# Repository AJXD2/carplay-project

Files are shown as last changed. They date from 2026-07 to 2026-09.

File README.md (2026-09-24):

# carplay Pi

A Raspberry Pi 4 CarPlay dongle box, turned into a small touchscreen
home screen with CarPlay as one app among a few others.

## Screenshots

The home screen, live on the 800x480 touchscreen. CarPlay gets the big
tile; everything else is one tap away, and the whole UI is sized for a
finger at arm's length:

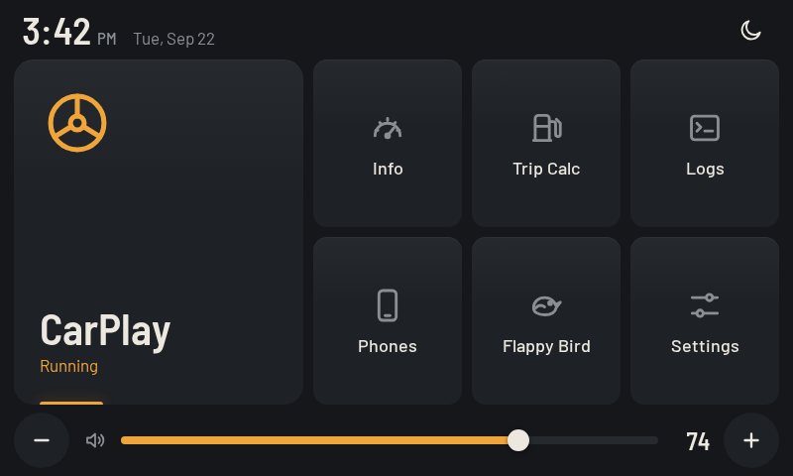
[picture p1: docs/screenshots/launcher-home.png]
Launcher home screen


CarPlay, one tile among the others:

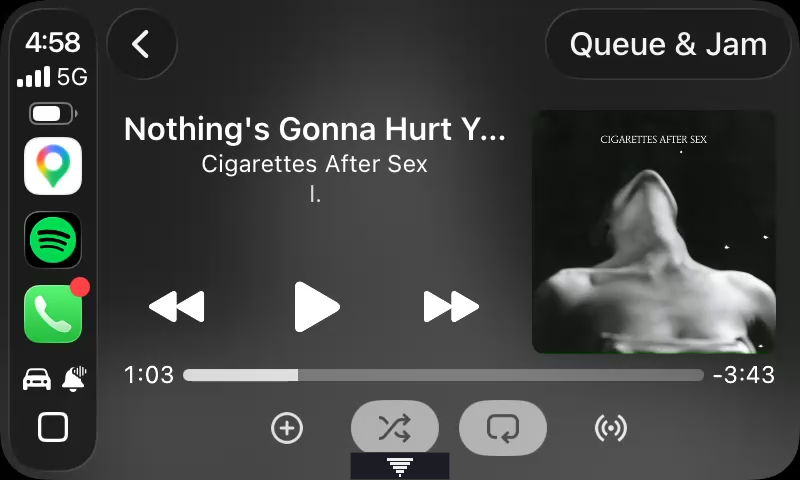
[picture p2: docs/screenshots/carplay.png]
CarPlay


| Info (live system status) | Trip Calc (fuel cost) |
|---|---|
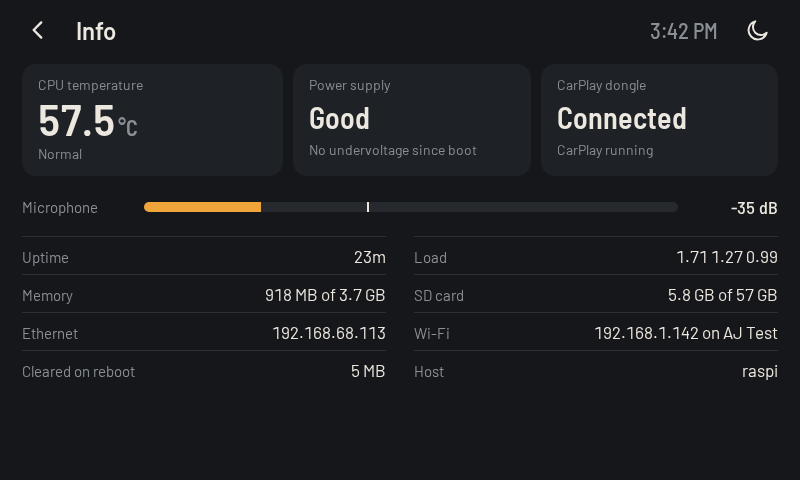
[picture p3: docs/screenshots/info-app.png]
Info
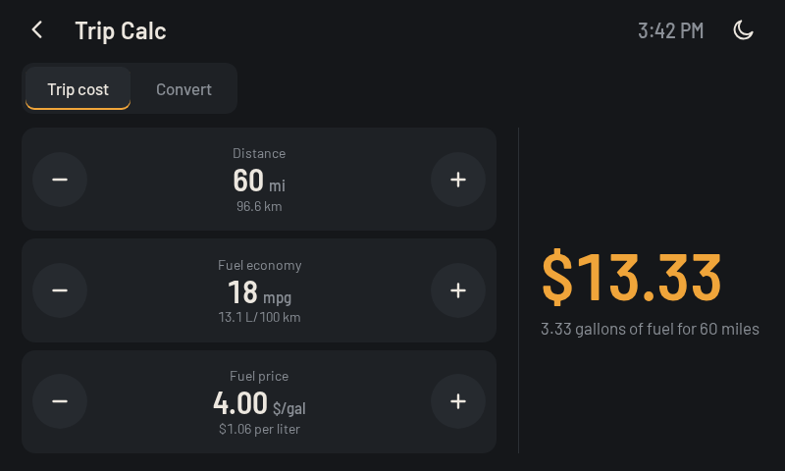
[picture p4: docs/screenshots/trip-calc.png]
Trip Calc
|  |  |

| Logs (on-screen tail) | Settings |
|---|---|
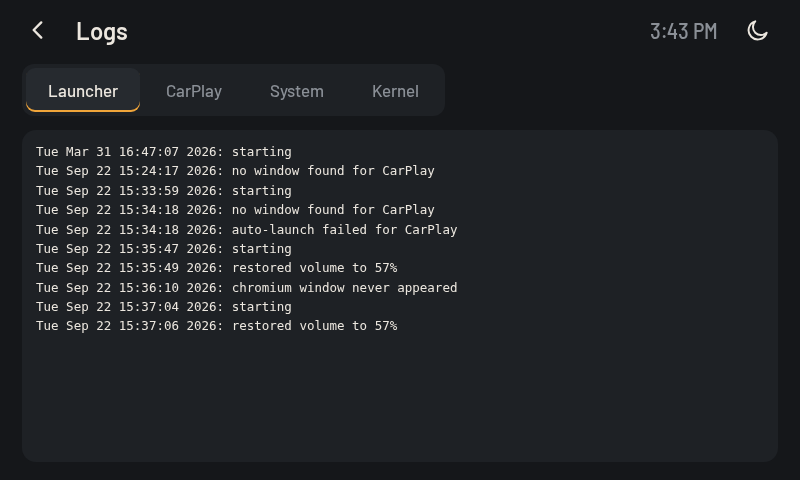
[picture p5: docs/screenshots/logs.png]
Logs
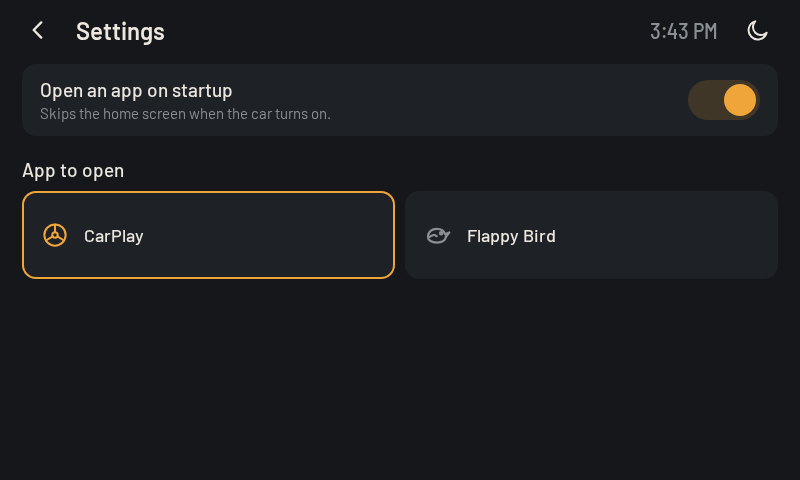
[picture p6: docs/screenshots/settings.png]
Settings
|  |  |

## What's here

- **`launcher/`**: the Chromium-kiosk home screen (Python backend +
  HTML/CSS/JS frontend) that autostarts on boot. CarPlay and Flappy Bird
  are separate apps it launches; Info, Trip Calc, Logs, Phones (the
  dongle's paired devices) and Settings are views inside the kiosk.
  Settings, trip values, volume and CarPlay's own config all survive
  reboots despite the read-only root.
- **`launcher/tools/`**: dongle tooling (web panel client, icon setter) and
  the react-carplay audio patch that fixes crackling.
- **`pi-monitor/`**: an on-screen alert system (via `dunst`) for CPU
  temp warnings and IP-address notifications, since CarPlay runs
  fullscreen with no window chrome to show that otherwise.
- **`hardware/carrier/`**: the in-truck board the Pi mounts on (power
  from the car, 4-channel amp, steering-wheel buttons, RTC, fans). Design
  in progress; see its [README](hardware/carrier/README.md).
- **`launcher/board/`**: `carrierd`, the service that runs that board
  (amp, wheel buttons, key-off shutdown, fans). Not deployed until the
  board exists.

## Quick start

Warning: the deploy scripts assume user `ajxd2` on host `raspi.local`;
edit [launcher/deploy.sh](launcher/deploy.sh) and
[pi-monitor/deploy.sh](pi-monitor/deploy.sh) for your own Pi.

```sh
ssh [user]@raspi.local            # SSH in
(cd launcher && ./deploy.sh)      # deploy launcher changes
(cd pi-monitor && ./deploy.sh)    # deploy pi-monitor changes
(cd launcher && python3 server.py --dev)   # work on the UI locally at http://127.0.0.1:8734
```

The Pi's root filesystem is **read-only at runtime**: a plain SSH edit
gets reverted on reboot. The deploy scripts handle writing through to
the real partition correctly; don't skip them.

## Full documentation

See **[INFO.md](INFO.md)** for everything else: hardware quirks, the
read-only-root persistence model in detail, networking, SSH access,
how the launcher and pi-monitor actually work, known limitations, and
a full command reference.

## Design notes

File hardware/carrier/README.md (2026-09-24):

# Carrier board (2007 4Runner head unit)

One board that turns the Pi 4 + 7" screen into a complete car radio
replacement. It bolts onto the Pi like a HAT, plugs into the truck's radio
harness, and does everything the factory radio did plus what the Pi needs:

- survives car power (reverse battery, load dump, cranking) and switches
  itself fully off with the key (a few µA left on the battery)
- powers the Pi, the screen and the fans (5 V, 6 A)
- drives the four stock speakers from the Pi's digital audio (no USB DAC,
  no ground-loop hum)
- reads the steering-wheel buttons (learn mode, any wheel)
- senses key, headlights (night mode) and reverse
- keeps the clock running with the power off
- runs two fans, and tells the Pi what it is at boot (HAT ID EEPROM)

Software for it lives in [`launcher/board/`](../../launcher/board/README.md).

## Status

| Stage | State |
|---|---|
| Schematic | Done. ERC 0 errors / 0 warnings. |
| Parts list (BOM) | Done. 148 fitted parts, every one with an LCSC number, stock checked at JLCPCB. |
| Placement | Done for the nominal Pi position. DRC: no overlaps or clearance errors. |
| Routing | Done. 0 unrouted, 0 DRC errors (silkscreen tidy pending), schematic parity 0. |
| Silkscreen tidy | Not started (cosmetic DRC items only). |
| Pi position on the screen | Measured on the real screen and confirmed with a printed fit test (see Mechanical). |
| Software | Written and tested on simulated hardware (18 tests), not installed. |
| Ordering | Not yet. |

## How it works, block by block

The schematic (`carrier.kicad_sch`, one A2 sheet, PDF in `out/carrier.pdf`)
is split into boxed sections. The same section names tag every part
(hidden `Section` field) so the board layout can find each block.

| Section | Parts | What it does |
|---|---|---|
| Harness | J1, Molex Micro-Fit 3.0 2x10 vertical | Truck wiring in; plug faces the firewall |
| Input protection | LM74800-Q1 + 2x BUK7Y4R8-60E + SMBJ33CA | Reverse-battery block, cuts off above 35.1 V (load dump), slow soft start (~2.5 V/ms). Its enable (SYS_EN) is the board's master switch |
| 5 V buck | LM61460-Q1, 4.7 µH | 5 V / 6 A at 400 kHz for Pi, screen (through GPIO pins 2/4 and the display's pogo pins), fans. Turns on at 6.0 V, off at 4.3 V, so it rides through cranking |
| 3.3 V | TLV75533 | Amp logic, ADC, RTC, EEPROM, clocks |
| Power hold + sensing | diodes, RC, 3x MMBT3904 | SYS_EN = key OR the Pi's hold line. Key/lights/reverse become active-low 3.3 V inputs |
| Amplifier | TAS6424E-Q1 | 4 x BTL, about 25 W/ch into 4 Ω at 14.4 V, 2.1 MHz switching, I2C controlled (0x6A) |
| Output filters | 8x 3.3 µH + 1 µF + 1 nF | Reconstruction filter per speaker leg (TI reference values) |
| Audio clocks | 12.288 MHz oscillator + PCM1808-Q1 | The board is the audio clock master (see decisions) |
| Mic input | 3.5 mm jack J4 (PJ-320D) into the PCM1808 | Electret car mic for calls and Siri: bias from 3.3 V, ESD and RF filtering at the jack, the PCM1808's ADC sends it to the Pi on GPIO20. Mic on the tip; ring and sleeve grounded |
| Status LEDs | 3 red 0603 (D8-D10), tagged 12V / 5V / PI | Which power stage is alive: protected 12 V, the 5 V rail, and the Pi holding the board on |
| Steering wheel + battery ADC | ADS1115 (0x48) | Two ladder inputs (1k pull-ups, ESD, RC filter), battery voltage on AIN2 |
| RTC + ID EEPROM | DS3231SN + CR2032 (0x68), CAT24C32 (0x50) | Clock through power-off; HAT ID per the Raspberry Pi HAT design guide |
| Pi | J2, 2x20 socket on the underside | Mates with the Pi's header |
| Fans | 2x 4-pin headers, 2N7002 each | PWM from the Pi, inverted by the FET; tach readback |
| Debug + mounting | UART header (not fitted), H1-H6 | Pi holes isolated per HAT spec; heatsink screws grounded |

## Design decisions and why

- **Class-D amp fed digitally (I2S).** The old setup went through a USB
  sound card; digital audio straight to the amp removes that and the
  ground-loop path. The TAS6424E-Q1 is automotive (AEC-Q100), survives
  40 V load dump, and was the only in-stock 4-channel part with digital
  input at JLCPCB.
- **The board is the audio clock master.** The Pi's PCM block carries only
  two channels, and the TAS6424 needs a real master clock (128-512 x the
  sample rate) outside TDM mode. So a 12.288 MHz oscillator drives the amp's
  MCLK directly and a PCM1808-Q1 in master mode (MD1 = MD0 = high, strapped,
  no software) divides it to the bit clock (64 fs) and frame clock
  (48 kHz). All three come from one crystal and cannot drift apart. The Pi
  runs its I2S port as a clock consumer. Consequences: audio is fixed at
  48 kHz (PulseAudio resamples), and the rear speakers play the same stereo
  as the front (SDIN1 and SDIN2 share the data); the fader and balance use
  the amp's per-channel volume. The CS2100 clock chip originally planned was
  dropped: JLC only stocks the -10 to 70 °C grade.
- **One master switch.** The LM74800's enable turns the whole board off.
  SYS_EN is the OR of the key (with a ~5 s RC grace period so a crank before
  the Pi boots does not cut power) and the Pi's own hold line (GPIO26). The
  Pi decides when to power off: key off for 8 s, then it shuts down cleanly,
  drops the hold line, and the board switches off about 2 s later. A hung Pi
  is reset by its watchdog, which also drops the hold line.
- **Steering wheel by learn mode.** Toyota wheels are resistor ladders on
  two wires. Instead of hard-coding resistor values, the software asks for
  each button once and remembers what it reads. It refuses two buttons it
  cannot tell apart.
- **Harness as one latching plug.** Every truck wire ends in one Micro-Fit
  plug (like a PC's ATX connector) that clicks into the board. 8.5 A per
  contact; 12 V and ground use several pins each.
- **Heatsink copied from TI's evaluation board.** The amp's thermal pad is
  on top of the chip. TI's EVM uses a custom 20 x 41.4 mm finned heatsink
  screwed down with M3 screws and Arctic Silver paste; ours is the same
  footprint with fins sized for CNC machining (`tools/heatsink.py`). Its
  feet sit on grounded pads, which grounds the heatsink as TI requires.
- **Part choices for car conditions.** Every IC is rated to at least 85 °C.
  Caps upstream of the 35 V cutoff are 100 V (the TVS can clamp to 53 V),
  the rest of the 12 V side is 50 V X7R. Speaker-filter 1 nF caps are C0G.
  Boot caps are 0603 (fit the amp's 0.635 mm pin pitch; datasheet asks for
  X7R ≥ 16 V, these are 50 V).
- **Fans fail safe.** The PWM FET's gate pull-down leaves the fans at full
  speed whenever the Pi is not driving them.

Full calculations (divider values, time constants, cut-off voltages) are
written as notes on the schematic next to each circuit.

## Mechanical

**Display:** Hosyond 7" DSI, **164.9 x 102.0 mm, 12.25 mm thick** per the
manufacturer's drawing (`datasheets/hosyond/`). The board uses the same
outline. Its own four mounting holes sit 5 mm in from each corner (154.89 x
91.92 mm apart): the enclosure screws into those, before the Pi and board go
on (the board sits ~18 mm above the screen's back, clear of the screw heads).

**Where the Pi sits on the screen.** First estimated from Hosyond's product
photo (the Pi's 58 x 49 mm hole pattern set the scale), then **measured on
the real screen** on 2026-09-24 with a printed fit plate and calipers, Pi
board edge to screen edge:

| Pi edge | To the screen edge |
|---|---|
| Ports side (USB/Ethernet) | 36.65 mm |
| Display ribbon side | 43.40 mm |
| GPIO side | 15.35 mm |
| USB-C / HDMI side | 31.45 mm |

The sums (165.05 x 102.80, all values rounded down) match the 165 x 103
screen. Left/right differed from the photo estimate by 1.35 mm, up/down by
under 0.2 mm. The plate's screw holes, header window and port notch all
lined up.

| Viewed from the back, from the display's top-left corner | mm |
|---|---|
| Upper Pi holes | x 60.15 and 118.15, y 35.1 |
| Lower Pi holes | x 60.15 and 118.15, y 84.1 |
| Pi outline | x 36.65 to 121.65, y 31.6 to 87.6 |
| Orientation | rotated 180°: GPIO header at the bottom, USB/Ethernet toward the right of the screen as seen from the front |

The manufacturer's drawing then confirmed the Pi holes at 60.36 / 118.36
mm from the screen's left edge and 35.19 / 84.19 mm from its top (within
0.2 mm of the measurements), and set the final outline.

How the correction is applied: the board is referenced to the Pi, so the
Pi, every part, the notch and the cable slot stay where they are and only
the outer outline moves (`OUTLINE_SHIFT` in `tools/place.py`). All copper was
routed at least 3 mm from the outer edges for exactly this; with the final
outline the edge margin is 2.5 mm.

**Board shape.** The Pi is mid-screen, so its USB/Ethernet block (13.5 mm
tall Ethernet jack, board sits 11 mm above the Pi) is ~30 mm in from the
display's edge. The board has a notch from the port block to the left edge
(back view): the jacks clear it and cables can reach them. A slot next to
the Pi's DSI connector clears the display ribbon (HAT spec position).

**Stack-up** (from the screen's glass, toward the firewall):

| Layer | z (mm) | Source |
|---|---|---|
| Display module | 0 to 6.0 | **assumed**, measure |
| Pi standoffs | 6.0 to 12.0 | **assumed**, measure |
| Pi 4 board | 12.0 to 13.6 | Pi spec |
| Header base + socket | 13.6 to 24.6 | 2.5 + 8.5 mm, HAT standard (11 mm M2.5 standoffs) |
| Carrier board | 24.6 to 26.2 | 1.6 mm |
| Tallest parts on it | to ~39 | 470 µF cap 12.5 mm, harness plug + mated housing |
| Heatsink fins | to 56.5 | 30.2 mm heatsink |

Overall **165 x 103 x 56.5 mm**. The heatsink sets the depth; shorter fins
(e.g. 15 mm) save ~13 mm at some cooling cost, which the fans make up.

**Fit test before ordering:** `tools/fit_plate.py` writes
`mech/fit_plate.stl`, a 1.6 mm plate with the board's exact outline, notch,
cable slot, Pi and heatsink holes and a window for the Pi header. Print it
text side up, mount it on the Pi with the 11 mm standoffs, and check the
edges against the screen and the holes against the standoffs.

**3D model:** `tools/assembly.py` builds display + Pi 4 + board + heatsink
(`mech/assembly.step`, `mech/assembly.stl`; generated, not committed).
Review images: `out/3d/*.png` via `tools/render3d.py`.

## Wiring the truck

The truck has three plugs behind the radio: two yellowish ones (power,
speakers; what the Metra harness mates with) and a white 20-pin one that
carries the steering-wheel wires. Build one Micro-Fit plug that gathers
them all:

- Power and speakers: the Metra harness wires, or the Klintotour adapter
  (which also has the white 20-pin plug). Either way the loose ends go into
  the Micro-Fit plug; nothing on the truck gets cut.
- Steering wheel: the Klintotour adapter's white-plug wires, cut from its
  16-pin end. Identify KEY1 and KEY2 with a meter (see below).
- Reverse: tap the truck's reverse-light wire (Posi-Tap) and run a wire to
  pin 10.

To build the plug: solder each wire to a pre-crimped Micro-Fit lead,
heat-shrink it, and push the pin into its numbered hole until it clicks.
Pin n sits directly above pin n+10. The speaker order (FR, FL, RR, RL) is
not a typo: it matches the amp's output order on the board, so the four
speaker tracks run straight to the plug without crossing.

| Pin | Signal | Typical wire colour |
|---|---|---|
| 1, 11 | +12 V constant | Yellow |
| 2, 12, 19 | Ground | Black |
| 7 | Key / accessory | Red |
| 17 | Headlights on (illumination) | Orange |
| 10 | Reverse (+12 V in reverse) | Pink "BACK" on the adapter, or your own wire |
| 8 | Steering wheel wire 1 (seek, volume) | KEY1 |
| 18 | Steering wheel wire 2 (mode) | KEY2 |
| 9 | Steering wheel ground | if separate; otherwise tie to ground |
| 3 / 13 | Front right + / − | Gray / gray-black |
| 4 / 14 | Front left + / − | White / white-black |
| 5 / 15 | Rear right + / − | Purple / purple-black |
| 6 / 16 | Rear left + / − | Green / green-black |
| 20 | Not used | |

Finding KEY1 / KEY2: adapter plugged into the truck, key off, meter on
ohms between each candidate wire and ground. The wire whose reading
changes with seek/volume is KEY1 (pin 8); the one that drops near 0 Ω on
Mode is KEY2 (pin 18). Earlier measurements on the purple SWC wire: seek+
~0 Ω, seek− 331 Ω, vol+ 100 Ω, vol− "3.111" (unit unclear). Learn mode
makes the exact values irrelevant.

Blue wires (power antenna, amp turn-on) are not used.

## Pi GPIO map

| Header pin | BCM | Net | Use |
|---|---|---|---|
| 2, 4 | 5V | +5V | Board powers the Pi (and the screen through its pogo pins) |
| 1, 17 | 3V3 | (unused) | The board makes its own 3.3 V |
| 3, 5 | GPIO2/3 | I2C_SDA/SCL | Amp 0x6A, ADC 0x48, RTC 0x68 (Pi has 1.8k pull-ups) |
| 27, 28 | ID_SD/SC | ID_SDA/SCL | HAT EEPROM 0x50 (3.9k pull-ups on the board) |
| 12 | GPIO18 | I2S_BCLK | Bit clock, **input** (board is master) |
| 35 | GPIO19 | I2S_FSYNC | Frame clock, **input** |
| 40 | GPIO21 | I2S_DOUT | Audio data to the amp |
| 32, 33 | GPIO12/13 | FAN1/2_PWM | Hardware PWM, 25 kHz, inverted |
| 36, 7 | GPIO16/4 | FAN1/2_TACH | Tach, 2 pulses/rev |
| 11 | GPIO17 | ~ACC_ON | Key on (active low) |
| 13 | GPIO27 | ~LIGHTS_ON | Headlights (active low, may be PWM-dimmed) |
| 38 | GPIO20 | I2S_DIN | Mic audio from the PCM1808, **input** |
| 26 | GPIO7 | ~REVERSE | Reverse gear (active low) |
| 37 | GPIO26 | PI_HOLD | Keeps the board powered while high |
| 15, 16 | GPIO22/23 | ~AMP_STBY/~AMP_MUTE | Amp control |
| 18, 22 | GPIO24/25 | ~AMP_FAULT/~AMP_WARN | Amp status (open drain) |
| 31 | GPIO6 | ~ADC_ALERT | ADC ready (unused by software for now) |
| 29 | GPIO5 | ~RTC_INT | RTC alarm |
| 8, 10 | GPIO14/15 | UART_TX/RX | Debug header (not fitted) |

## Shopping list (besides the board)

From DigiKey (genuine Molex; Amazon does not carry the 20-way housing):

| Qty | Part | Link |
|---|---|---|
| 2 | Micro-Fit 3.0 2x10 plug housing, Molex 43025-2000 | [DigiKey](https://www.digikey.com/en/products/detail/molex/0430252000/531408) |
| 25 | Micro-Fit pre-crimped lead, socket + 300 mm 18 AWG, Molex 2147611124 | [DigiKey](https://www.digikey.com/en/products/detail/molex/2147611124/12353036) |
| opt. | Micro-Fit extraction tool, Molex 11-03-0043 (the Amazon "11-03-0044" tools are Mini-Fit Jr, wrong size) | [DigiKey](https://www.digikey.com/en/products/detail/molex/0011030043/252489) |

From Amazon:

| Qty | Part | Link |
|---|---|---|
| 1 | Klintotour Toyota adapter (for the white steering-wheel plug) | [B0FBRNCNPD](https://www.amazon.com/dp/B0FBRNCNPD) |
| 1 | CR2032 | [B07G7KRQQ5](https://www.amazon.com/dp/B07G7KRQQ5) |
| 1 | M2.5 standoffs, 11 mm body + 6 mm thread | [B07KM27KC6](https://www.amazon.com/dp/B07KM27KC6) |
| 2 | Noctua NF-A4x10 5V PWM (each includes an extension cable) | [B07DXS86G7](https://www.amazon.com/dp/B07DXS86G7) |
| 1 | Posi-Tap 18-24 AWG | [B01HSBYX3I](https://www.amazon.com/dp/B01HSBYX3I) |
| 1 | 18 AWG wire (reverse run) | [B07D74RGVM](https://www.amazon.com/dp/B07D74RGVM) |
| 1 | Heat-shrink assortment | [B01MFA3OFA](https://www.amazon.com/dp/B01MFA3OFA) |
| opt. | 4-pin PWM fan extensions | [B0CNLDNZB2](https://www.amazon.com/dp/B0CNLDNZB2) |

With the board order (JLCPCB): the heatsink as a CNC part from
`mech/heatsink.step` plus `mech/heatsink_drawing.pdf` (threads, tolerances):
6061-T6 aluminium, **no surface finish** (anodising would insulate it; it is
grounded through its feet), two M3 threads in the feet, foot height
2.20 +/-0.05 mm. Also needed: thermal paste (Arctic MX-4 or similar) and two M3 x 5 mm
screws (they go up through the board into the heatsink).

## Files

| Path | What |
|---|---|
| `carrier.kicad_sch` / `.kicad_pcb` / `.kicad_pro` | KiCad 10 project (generated, see below) |
| `lib/carrier.kicad_sym`, `lib/carrier.pretty/` | Custom symbols and footprints |
| `lib/ref/` | EasyEDA/JLC reference symbols and footprints used to check pinouts |
| `datasheets/` | Every datasheet used, plus the HAT mechanical drawing and TI's EVM guide |
| `mech/heatsink.step`, `.stl` | Heatsink for CNC |
| `tools/` | Generators and checks (below) |
| `out/` | Renders, PDF, BOM, reports (generated, not committed) |

## Regenerating everything

The schematic and board are produced by scripts, not edited by hand, so
every value and position is reviewable in one place. KiCad runs as a
Flatpak; `kicad-cli` is a wrapper in `~/.local/bin`. The Python virtualenv
`.venv` holds `easyeda2kicad`, `cadquery` and `matplotlib`.

```bash
cd hardware/carrier
python3 tools/make_symbols.py            # lib/carrier.kicad_sym
python3 tools/gen_sch.py                 # carrier.kicad_sch (part numbers included)
python3 tools/render.py                  # out/sch/full.png, plus crops: render.py name x1 y1 x2 y2
kicad-cli sch erc -o out/erc.rpt carrier.kicad_sch
kicad-cli sch export pdf -o out/carrier.pdf carrier.kicad_sch
kicad-cli sch export bom --fields 'Value,Reference,Footprint,LCSC,MPN,Manufacturer,${QUANTITY},${DNP}' \
  --labels 'Comment,Designator,Footprint,LCSC,MPN,Manufacturer,Qty,DNP' \
  --group-by 'Value,Footprint,LCSC,${DNP}' --exclude-dnp -o out/bom_jlcpcb.csv carrier.kicad_sch

tools/build_board.sh                     # placement, planes, hand routes, Freerouting, finish, DRC (~20 min)
tools/build_board.sh noauto              # stop before the autorouter
flatpak run --command=python3 org.kicad.KiCad tools/dump_pcb.py   # then:
.venv/bin/python tools/view_pcb.py NAME [x0 y0 x1 y1] [--nets TEXT] [--labels]   # out/pcb/NAME.png
.venv/bin/python tools/fit_plate.py      # mech/fit_plate.stl

.venv/bin/python tools/heatsink.py       # mech/heatsink.step/.stl
kicad-cli pcb export step --subst-models --force -o mech/carrier_board.step carrier.kicad_pcb
.venv/bin/python tools/assembly.py       # mech/assembly.step/.stl
.venv/bin/python tools/render3d.py       # out/3d/*.png
```

What each script owns:

- `make_symbols.py`: custom symbols (TAS6424, LM61460, LM74800, DS3231,
  PCM1808, harness, Pi header). Pin numbers and names were checked against
  datasheets / EasyEDA each time a symbol was rearranged.
- `gen_sch.py` + `schlib.py`: the schematic. Each section is a function
  placed at an anchor; `PARTS` maps (value, footprint) to MPN /
  manufacturer / LCSC. Part UUIDs are derived from references, so reruns are
  byte-identical and the board stays linked to the schematic.
- `gen_pcb.py` + `place.py`: board outline, 4-layer stackup, JLC design
  rules, net classes and placement. `place.py` holds the Pi position, the
  notch/slot geometry and every block's layout, with parts found by
  Section field and nets.
- `route.py`: everything that carries current or needs care, locked so the
  autorouter works around it. In1 is solid GND; In2 is split into
  +12V_PROT (protection, amp, buck input) and +5V (buck output, Pi, LDO,
  clocks, fans). Top-layer pours for the battery path, VMID, buck VIN/PGND/SW
  and output, amp PVDD and the Pi's 5 V pins. Hand-routed amp outputs (P legs
  on top, M legs dropped to the bottom under the coils) and speaker lanes
  (1 mm, nested so none cross). Every GND pad gets its own via to In1, and
  +5V/+12V pads over their In2 region likewise. The LM74800's 0.5 mm pins
  and a few tight nets are routed by `maze.py` (a small grid router).
  Nothing copper within 3 mm of the outer edge.
- `autoroute.py` exports to Freerouting (with keepouts guarding the pours)
  and imports the result; `finish.py` maze-routes anything left open.
- `heatsink.py`, `assembly.py`, `render3d.py`: mechanical.

## Verification so far

- ERC: 0 errors, 0 warnings.
- Netlist check: every Pi GPIO lands on its intended net; amp pins, speaker
  filters and clock nets checked net by net.
- Board: 0 schematic-parity issues; no courtyard overlaps or clearance
  errors; parts clear of the Pi socket's solder pins by 3 mm; only parts
  under 2.2 mm under the heatsink.
- BOM: 148 fitted parts, all LCSC numbers present and in stock when chosen
  (2026-09-22/24).
- Pi socket orientation: pin 1 over the Pi's pin 1, checked by pad position
  (a mirrored socket would put 5 V on the wrong pins).
- Software: 18 tests on simulated hardware, including the GPIO request
  struct compared byte for byte with `<linux/gpio.h>`.

## Open items

1. ~~Fit check~~: done 2026-09-24, the corrected outline (`mech/fit_frame.stl`)
   fits the screen, screw holes, header and port notch exactly.
2. Measure display thickness and the display-to-Pi standoff height (3D
   model only).
3. Tidy silkscreen; add the harness pin table next to J1.
4. Final review (renders, BOM, cost), then order: board + assembly + CNC
   heatsink from JLCPCB.
5. On first power-up: confirm the react-carplay window class used for
   steering-wheel keys, run learn mode, check amp start-up and fault
   handling on real hardware, and check the mic capture path (the overlay
   puts two dummy codecs on one I2S link; set mic gain in software).

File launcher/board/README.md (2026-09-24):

# carrierd: carrier board services

Software for `hardware/carrier`: the TAS6424 amp, steering-wheel buttons,
key-off shutdown, headlights/reverse inputs and the fans. Standard library
Python only; the I2C and GPIO access uses the kernel interfaces directly.

| File | What it does |
|---|---|
| `carrierd.py` | Daemon: main loop, actions, local API on `127.0.0.1:8735` |
| `tas6424.py` | Amp bring-up (datasheet order), fader, fault recovery, thermal trim |
| `swc.py` | ADS1115 reader, button decoder with hold-repeat, learn mode |
| `power.py` | Key-off timer (rides out cranking), PWM-dimmer averaging, debounce |
| `fans.py` | Fan curve, tach RPM (the PWM is inverted by the board's FET) |
| `hw.py` | I2C (`I2C_RDWR`), GPIO chardev v2, sysfs PWM, plus simulated twins |
| `sim.py` | Register models of the TAS6424 and ADS1115 |
| `system/` | `config.txt` lines, the I2S overlay, the systemd unit |

Test on any machine (the GPIO test compiles against `<linux/gpio.h>` to
check the struct layout byte for byte):

    cd launcher && python3 -m unittest board.test_board -v
    python3 -m board.carrierd --sim        # runs the loop on simulated hardware

## Install (once the board is built)

Not part of `deploy.sh` yet, since nothing here should run without the board.

1. Append `system/config.txt` to `/boot/firmware/config.txt`.
2. `sudo apt install device-tree-compiler`, then
   `sudo dtc -@ -I dts -O dtb -o /boot/firmware/overlays/carrier-audio.dtbo system/carrier-audio-overlay.dts`.
3. PulseAudio must run at the board's fixed 48 kHz: in `/etc/pulse/daemon.conf`
   set `default-sample-rate = 48000` and `alternate-sample-rate = 48000`.
4. Copy `board/` to `/home/ajxd2/launcher/board`, install
   `system/carrierd.service` to `/etc/systemd/system/`, `systemctl enable carrierd`.
5. Persist all of the above to `/media/root-ro` (see INFO.md), reboot.
6. Learn the steering wheel: `curl -X POST 127.0.0.1:8735/learn/start`, press
   each button as `GET /state` prompts (`/learn/skip` for buttons the wheel
   lacks). A launcher screen for this comes with the board bring-up.

Things to confirm on the real hardware: the CarPlay window class used for
key injection (`carplay_window_class`, default `react-carplay`) and the
wheel's button readings.

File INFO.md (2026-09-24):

# carplay Pi

Notes and tooling for the Raspberry Pi 4 CarPlay dongle box. This repo
exists because the Pi's root filesystem is read-only at runtime, so
nothing done directly on the device persists unless you go through one
of the methods documented below. Read this before you SSH in and start
changing things: it *will* get reverted on reboot otherwise.

See [README.md](README.md) for an overview and screenshots.

## Hardware / OS

- **Raspberry Pi 4**: USB-C port is power-only, no OTG/gadget mode. USB-A
  ports are host-only too. There is no way to get a terminal over a USB
  cable on this board; use the network or GPIO UART.
- Raspberry Pi OS (Debian trixie), kernel `6.12.47+rpt-rpi-v8`.
- Hostname: `raspi`. User: `ajxd2`.
- Power: needs a genuine 5.1V/3A USB-C PD supply into a wall outlet. A
  computer's USB port or a cheap/thin cable will trigger an undervoltage
  warning and throttle the CPU / risk SD corruption. There's no
  "raise the voltage" fix, it's a current-delivery problem, not a
  software setting. (`avoid_warnings=1` in `config.txt` only hides the
  icon, doesn't fix the actual undervoltage: don't use it as a fix.)

## Read-only root (`overlayroot`): the most important thing to understand

The Pi boots with `overlayroot="tmpfs:recurse=0"` (see
`/etc/overlayroot.conf`). This means:

- The real filesystem (`/dev/mmcblk0p2`, ext4) is mounted **read-only**
  at `/media/root-ro`.
- Everything else (`/`, `/home`, `/etc`, ...) is a **tmpfs overlay** on
  top of that, `upperdir=/media/root-rw/overlay`.
- Anything written while the Pi is running normally (`apt install`,
  editing a config file, anything) goes into that tmpfs upper layer
  and is **gone on the next reboot or power cycle**.

This is intentional and correct for a device that gets its power cut
abruptly (car ignition off) instead of shut down cleanly. It protects
the SD card from corruption. Don't disable it permanently; work with
it instead.

### How to make a change actually persist

Two ways, both write straight to the real ext4 partition, bypassing
the tmpfs overlay entirely:

**A. Over SSH, while the Pi is running (preferred, no physical access needed):**

```sh
# Remount the real partition read-write:
ssh ajxd2@raspi.local 'sudo mount -o remount,rw /media/root-ro'

# Then write files under /media/root-ro/... instead of the normal path, e.g.:
ssh ajxd2@raspi.local 'sudo tee /media/root-ro/home/ajxd2/some-file'

# For anything needing a proper package-manager/root context (apt installs etc),
# use the overlayroot-chroot helper instead of remounting manually:
ssh ajxd2@raspi.local 'sudo overlayroot-chroot apt-get install -y <pkg>'
# (No "--" before the command: overlayroot-chroot <cmd...> directly.)

# Best-effort remount back to read-only when done:
ssh ajxd2@raspi.local 'sudo mount -o remount,ro /media/root-ro'
```

**Known kernel quirk:** the remount back to `ro` frequently fails with
`mount point is busy` while the overlay is actively mounted on top of
it. This is non-fatal, it just means the real partition stays
writable for the rest of this boot session (same power-loss-corruption
risk as a normal filesystem until next reboot). It always resets
cleanly to read-only on the next boot regardless. If you want the
protection back immediately, `sudo reboot`.

**Another quirk:** overlayfs caches directory listings the first time
something is looked up. If you install a new package (new files
appearing in an already-accessed directory like `/usr/bin`), those new
files **will not show up in the live session**, you have to `sudo
reboot` for the overlay to remount fresh and pick them up. Writing a
brand-new file into a path that's never been touched this boot (e.g. a
new subdirectory under `/home/ajxd2/`) *does* show up live immediately
via the overlay's fallthrough-to-lower behavior. When in doubt, reboot
to be sure.

**B. Offline, by pulling the SD card:**

Mount it on another machine (rootfs partition is `ext4`, boot partition
is `vfat`), edit files directly, unmount, put it back. Slower, but
useful if the Pi won't boot / network is unreachable / you need to fix
something SSH-related itself (like `authorized_keys`).

```sh
lsblk -f                              # find the device, e.g. /dev/sdb
udisksctl mount -b /dev/sdb2          # mounts rootfs at /run/media/$USER/rootfs
udisksctl mount -b /dev/sdb1          # mounts boot partition at .../bootfs
# ... edit files under /run/media/$USER/rootfs/... ...
udisksctl unmount -b /dev/sdb2
```

If your local user has the same UID as `ajxd2` on the Pi (id 1000),
you can write to `ajxd2`-owned files without `sudo` at all.

## Networking

- `systemd-networkd` (enabled) does DHCP on both `eth0` and `wlan0`.
  Configs at `/etc/systemd/network/10-eth0.network` and
  `20-wlan0.network`. **Not** `dhcpcd` (present but unused/not enabled).
- Wi-Fi auth is `wpa_supplicant@wlan0.service` (enabled), config at
  `/etc/wpa_supplicant/wpa_supplicant-wlan0.conf` (root-only, `600`).
- `NetworkManager.service` is also enabled but effectively inert:
  `system-connections/` is empty and `NetworkManager.conf` sets
  `managed=false` for ifupdown. It's a leftover, not what's actually
  bringing interfaces up. Ignore it.
- `avahi-daemon` was **masked** (`/etc/systemd/system/avahi-daemon.service`
  symlinked to `/dev/null`) out of the box, which is why `raspi.local`
  didn't resolve. We unmasked and enabled it (done, persisted). If a
  fresh image ever has this problem again:
  ```sh
  sudo rm /media/root-ro/etc/systemd/system/avahi-daemon.service
  sudo ln -s /lib/systemd/system/avahi-daemon.service \
    /media/root-ro/etc/systemd/system/multi-user.target.wants/avahi-daemon.service
  ```
  (or the SSH-live equivalent using `overlayroot-chroot`).

## SSH access

- `authorized_keys` lives at `/home/ajxd2/.ssh/authorized_keys` (was
  empty, that's why a new machine couldn't get in). Add a new laptop's
  key by appending its `~/.ssh/id_ed25519.pub` to that file (through
  one of the persistence methods above, not a plain live SSH edit, or
  it'll disappear on reboot).
- `PasswordAuthentication` is commented out (defaults to whatever
  sshd's compiled default is, currently pubkey-only in practice since
  no password login has worked). Pubkey is the supported path.
- The `ajxd2` account has **passwordless sudo**, and UID 1000 matches a
  typical single-user Linux desktop, which is how the SD-card-editing
  trick above works without needing the Pi's password at all.

## The CarPlay dongle itself (Carlinkit CPC200-CCPA)

The physical dongle enumerates as USB `1314:1521` (`Magic Communication
Tec.` / `Auto Box` in the descriptors, broadcasting as `AutoKit-8169`
over WiFi/BT), and is a genuine Carlinkit CPC200-CCPA (confirmed from
the printing on the physical unit) -- an i.MX6UL-based embedded Linux
board, 16MB flash. It reports `boxType: YA`, `productType: A15W`,
`hwVersion: YMA0-WN16-0003`, software `2025.02.25.1521CHY`.

`react-carplay`/`node-carplay` (the app this repo runs) talks to it
over a simple bulk-USB wire protocol reverse-engineered upstream in
`rhysmorgan134/node-CarPlay`'s `src/modules/messages/{common,sendable,
readable}.ts`. Worth knowing if you ever need to script against the
dongle directly (`python3-usb`, install via `sudo overlayroot-chroot
apt-get install -y python3-usb`, works fine for this since it's just
bulk transfers on a vendor-specific interface):

- **Reads available**: manufacturer/serial (USB descriptor), software
  version, box identity/config including the full **paired-device
  list** (`BoxInfo.DevList` -- MAC, name, index, per device), a
  separate raw `BluetoothPairedList` string, box's own WiFi/BT name,
  a live HiCar pairing link, and now-playing media (song/artist/album
  art -- this is genuinely live personal data, be careful taking
  screenshots of a running session).
- **Writes available**: night mode, WiFi band, media transport
  commands, accept/reject call, and file-based cosmetic config
  (`SendFile` to `/etc/box_name`, `/etc/airplay.conf`,
  `/etc/icon_*.png` etc) -- see `launcher/tools/set_dongle_icon.py`,
  which sets a custom name + icon on the phone's CarPlay home-screen
  tile using exactly this mechanism. **File writes to `/etc/` on the
  dongle appear to only take effect after a physical power-cycle of
  the dongle itself** (unplug/replug), not just a CarPlay app restart.
- **Device removal is NOT in the USB protocol -- but it exists in the
  dongle's own web admin panel.** Over the USB wire protocol there is no
  remove/forget command (confirmed: tried the documented set plus
  `BoxSettings` (0x19) writes carrying `DevList`/`delDevList`/`removeDev`
  fields, plus `SendFile` to guessed paired-store paths, plus a real
  physical power-cycle -- the `DevList` survived all of it). The removal
  capability lives instead in the dongle's **built-in HTTP admin panel**,
  which the USB investigation never looked at:
  - The dongle runs a WiFi AP `AutoKit-8169` (WPA2-PSK, password
    `12345678`, BSSID `00:e0:4c:64:1b:24`). Joining it gets a DHCP lease
    on **`192.168.43.0/24`** (this unit -- *not* the `192.168.50.x` the
    generic Carlinkit docs claim), with the panel at
    **`http://192.168.43.1`** (a Vue SPA). The Pi has a single `wlan0`,
    so joining this AP drops the Pi's own network unless it also has
    `eth0` up -- pin SSH to the `eth0` IP first, then repurpose `wlan0`.
  - The panel's entire API is one endpoint: `POST /cgi-bin/server.cgi`,
    multipart form fields `cmd` / `item` / `val` / `ts` (ms) / `sign`
    (md5, computed by the panel JS). Observed calls:
    - **Remove one paired device:** `cmd=set, item=delDev,
      val=<MAC>` -> `{"err":0}`. Verified: removing `A4:CF:99:0B:A3:16`
      dropped the box's `DevList` from 4 to 3, confirmed by an
      independent USB `BoxInfo` read afterward.
    - Read full state (incl. `DevList`, `Settings`, `BoxInfo`):
      `cmd=infos`.
    - Reboot the dongle: `cmd=restart`.
  - Using the panel UI from a phone (join the AP, browse to
    `192.168.43.1`, delete the device) is the easy path -- the JS signs
    requests for you. It can also be scripted headless: the signing was
    reverse-engineered and `launcher/tools/ccpa_panel.py` implements it
    (see the full API section below).
  - Simpler alternatives that also work: the phone's own Settings ->
    General -> CarPlay -> (car) -> "Forget This Car", or a full wipe via
    the panel's factory reset / the physical pinhole reset button (clears
    ALL pairings + WiFi/BT config, so every phone re-pairs).
- **Don't bother with alternate/custom firmware.** Carlinkit added an
  activation-lock mechanism (`/etc/uuid_sign`) after community
  reverse-engineering became known to them; a firmware that fails
  activation has no known unlock path. There's also no documented live
  root/shell access to this hardware (no UART/SSH/telnet), only
  hardware flash programming, which isn't worth the bricking risk --
  especially now that device management is reachable through the stock
  web panel above without touching firmware at all.

### The dongle web panel API (`server.cgi`) -- full map

The panel at `http://192.168.43.1` is a Vue SPA; its entire backend is
one endpoint, `POST /cgi-bin/server.cgi` (multipart/form-data). Client:
`launcher/tools/ccpa_panel.py` (stdlib-only, works headless or through
an `ssh -D` SOCKS tunnel with `--proxy socks5h://127.0.0.1:1080`).

**Request signing** (reversed from `PublicV2.js` `signFormData`, verified
byte-for-byte against captured requests):

- Every request carries `ts` (epoch ms) and `sign`.
- `sign = md5( "k1=v1&k2=v2&..." + SALT )` where the pairs are all the
  other fields (`cmd`, `item`, `val`, `ts`, ...), **keys sorted
  ascending**, joined by `&`. `SALT = "HweL*@M@JEYUnvPw9G36MVB9X6u@2qxK"`
  (hardcoded in the JS bundle).
- Empty `item`/`val` are omitted entirely (not sent as empty) -- send
  them and the signature won't match, you get `403`.
- Only the activation call (`cmd=a`) already contains a field named
  `sign` (a cloud-issued one); `signFormData` renames it to `sg` before
  computing its own `sign`.

**Commands seen in the bundle / verified live:**

| `cmd` | args | effect | kind |
|---|---|---|---|
| `infos` | -- | full state: `CarInfo`, `BoxInfo`, `Settings` (49 keys), `DevList`, `LangList`, `WifiChannelList` | read |
| `BoxMonitor` | -- | live dongle telemetry: `CpuRate`, `CpuTemp`, `CpuFreq`, `MemRate`, `WifiRX`, `WifiTX` | read |
| `upgradeState` | -- | firmware-update progress: `err`, `progress`, `failReason` | read |
| `logFile` / `appLogFile` / `sdkLogFile` | -- | download an obfuscated log blob (prefixed `^^^^$$$`, ~MBs) | read |
| `set` | `item`,`val` | change one thing (see items below) | write |
| `carInfo` | `brand`/`model`/`year`/`userid` | set the car identity shown in the panel | write |
| `restart` | -- | reboot the dongle | action |
| `reset` / `resetApp` | -- | confirm-dialog resets in the UI (settings/app reset); **not tested here** -- treat as destructive | action |
| `a` | `is`,`code`,`sign`(->`sg`),`tabId`,`burnType` | activation handshake (ties to `BoxInfo.needActive=1` + the cloud call to `file.paplink.cn/ad/a/upgrade/check2Box`) | action |

**`cmd=set item=<...>`** items are the `Settings` keys from `infos`. The
panel bundle knows about 49 (`fps`, `gps`, `lang`, `micGain`, `MicMode`,
...), but **this unit's firmware only reports 14**: `CallQuality`,
`ScreenDPI`, `Udisk`, `autoConn`, `autoPlay`, `backRecording`, `bitRate`,
`displaySize`, `mediaDelay`, `mediaSound`, `naviVolume`, `startDelay`,
`wifi5GSwitch`, `wifiChannel`. Special items: **`delDev`** (`val=<MAC>`,
removes a paired device -- the whole point), `resetLogo` (`val=""`), and
`lang` (special-cased in the JS).

Two settings matter for audio (see "Audio" below):

- **`CallQuality`**: 0 = Norm, 1 = Clear, 2 = HD. **Must be 0 here.** At HD
  (2), the far end of a phone call hears nothing from the car mic, while
  Siri works fine. react-carplay always sends mic audio as 16 kHz mono, and
  HD call mode evidently expects something else. Set with
  `ccpa_panel.py set CallQuality 0`; it's stored on the dongle.
- **`mediaDelay`**: the dongle's audio jitter buffer in ms (panel default
  1000, range 300-2000). Setting it here is pointless: react-carplay
  overwrites it on every connect from its own `config.json`
  (`BoxSettings { mediaDelay }`), so change it there instead.

Quick examples:

```sh
# on a machine joined to the AutoKit-8169 AP (or add --proxy for a tunnel)
python3 launcher/tools/ccpa_panel.py listdev            # paired devices
python3 launcher/tools/ccpa_panel.py deldev A4:CF:99:0B:A3:16
python3 launcher/tools/ccpa_panel.py monitor            # cpu/temp/mem
python3 launcher/tools/ccpa_panel.py get wifiChannel
python3 launcher/tools/ccpa_panel.py set wifiChannel 149
```

To reach it from the Pi without a phone: the Pi's `wlan0` can join the
AP (see `AutoKit-8169`/`12345678` above) while SSH stays on `eth0`; or a
laptop can `ssh -D 1080 -N ajxd2@<pi-eth0-ip>` and point the tool at
`--proxy socks5h://127.0.0.1:1080`.

## What's actually running

- `launcher/server.py` (see below) is what autostarts, not
  `react-carplay.AppImage` directly. CarPlay is one of its apps.
- Desktop stack: `agetty` autologin on `tty1` → `.xinitrc` → `Xorg` →
  `openbox` (window manager) → autostart script launches the launcher +
  overlay tab, `pulseaudio`, `picom` (compositor), `unclutter`, `dunst` +
  `pi-monitor.sh` (see below).
- `picom` config lives in the repo at `launcher/system/picom.conf` (deployed
  by `launcher/deploy.sh`). App switching is an X unmap + map, which picom
  animates: the incoming app grows in from 96% as it fades up, the
  outgoing one fades out, and dunst notifications slide down from the top.
  It must stay on the `xrender` backend: the Pi's GPU fails picom's GL
  shader check (`GLSL 3.30 is not supported`). If picom dies, windows still
  draw, just without effects.
- No Docker, no other custom services beyond stock Bluetooth/PulseAudio.

## launcher: CarPlay as one app among others

`launcher/` turns this from a single-purpose CarPlay box into a small
home screen with CarPlay as one tile among a few others (Flappy Bird, a
live system-status app, a trip/fuel-cost calculator, a log viewer), all
controllable via touch, since the car has no keyboard.

The home screen is a **Chromium kiosk** (HTML/CSS/JS UI served by a small
local Python backend), not the original pygame implementation -- pygame's
`FINGERDOWN` touch handling never reliably registered real touchscreen
taps on this hardware (simulated X11 clicks worked fine, which is exactly
what made the bug hard to catch -- real touch and simulated clicks are not
the same code path in SDL), while Chromium's touch handling is the same
stack CarPlay's own Electron app already uses reliably on this device.

- **`launcher/server.py`**: the backend, started by a respawn loop in
  openbox autostart. Stdlib-only (`http.server.ThreadingHTTPServer` -- no
  `pip`/Flask on this device, deliberately not installed for this). Owns
  the `APPS` list (only the real separate programs: CarPlay and Flappy
  Bird), process/window state, config, volume, and the JSON API the
  frontend calls: `/api/status` (one poll for app state, dongle presence,
  volume, night mode, clock sync), `/api/launch`, `/api/volume`,
  `/api/config`, `/api/dim`, `/api/info`, `/api/mic`, `/api/trip`,
  `/api/logs?source=launcher|carplay|system|kernel`, `/api/devices*`.
  Startup order: bind the HTTP port first, hand `wlan0` back if a previous
  run died mid-Phones-view, **kill any stale kiosk Chromium / CarPlay /
  Flappy left by a previous run** (a respawned server can't re-attach to
  them, and two CarPlays fight over the dongle's USB interface), start the
  persistence watcher and volume keeper, start Chromium, auto-launch.
  - Chromium's window gets `wm_helper.make_override_redirect()` applied
    once at startup: Chromium's kiosk/fullscreen state is *dynamic* (tied
    to visibility), so the plain unmap/map cycle `hide_window()`/
    `show_window()` use would otherwise let openbox re-decorate it
    (titlebar, borders, black margin) the first time you switch away and
    back. Override-redirect makes the WM stop managing the window, and it's
    re-pinned to `0,0 800x480`.
  - Wipes `/tmp/chromium-kiosk-profile` on every start: a leftover
    `SingletonLock` can make a fresh Chromium silently refuse to open.
  - **Window capture and X id reuse.** Apps are captured by waiting for
    focus to move to a new, big-enough window. When an app is killed and
    restarted, X can hand the new window the *same id* the dead one had,
    and openbox keeps reporting the dead id as active, so "focus moved to a
    new window" never fires (this showed up as "chromium window never
    appeared" and "no window found for CarPlay"). `get_active_window()`
    now ignores ids that no longer exist, and if the wait still times out,
    `find_window_for_pid_tree()` finds the app's window by process.
  - Each app's stdout/stderr goes to `/tmp/<app>.log`; CarPlay runs with
    `--enable-logging=stderr`, so `/tmp/carplay.log` has react-carplay's
    renderer console (`starting mic`, `UNDERFLOW`, connect events).
  - Night mode: the moon button writes `/sys/class/backlight/*/brightness`
    (`ajxd2` is in `video`, no sudo) so the whole physical screen dims,
    CarPlay included, and switches the launcher to a warmer, darker palette.
  - `python3 server.py --dev` serves the UI locally without Chromium, X, or
    any writes to `/media/root-ro`, for frontend work on another machine.
- **`launcher/web/`**: the frontend, plain HTML/CSS/JS, no build step, fonts
  bundled in `web/fonts/` (Barlow, OFL) since the device is usually offline.
  "Dash" style: graphite surfaces and one accent color, instrument-cluster
  amber, for anything lit (running app, active control, volume level). Home
  is a big CarPlay tile plus a 3x2 grid; everything else is an in-page view
  with a Back button, switched by `showView()` in `app.js`:
  - **Info**: CPU temp, power (undervoltage), dongle presence on USB, a live
    **microphone level meter** (samples the default source with `parec`),
    memory, SD card, IPs, and "cleared on reboot" (overlay RAM in use).
  - **Trip Calc**: trip fuel cost + unit conversion, press-and-hold
    steppers, values persisted across reboots.
  - **Logs**: launcher, CarPlay, system journal, kernel; native touch
    scrolling with a jump-to-newest button.
  - **Phones**: the dongle's paired phones, via its web panel (below).
  - **Settings**: open CarPlay or Flappy on startup; applies on tap.
  - The clock shows `--:--` / "Clock not set" until NTP has synced, rather
    than the stale time the Pi boots with (see "Clock" below).
- **`launcher/wm_helper.py`**: shared window-management + audio helpers
  used by `server.py` and `overlay_tab.py`: window capture (above), hide/
  show, override-redirect, and `apply_audio_priority(binary)`: **CarPlay
  always has audio priority**, its sink-inputs are unmuted on every app
  switch and whatever else is active gets muted instead.
- **`launcher/persist.py`**: all write-through to the real partition (see
  "Runtime state that survives reboot" below).
- **`launcher/overlay_tab.py`**: a small always-on-top "go home" tab,
  bottom-center of the screen. Built as a raw X11 **override-redirect**
  window (via `python3-xlib`) so it floats above *any* fullscreen app
  including CarPlay. Tapping it hides whatever's active and shows the
  launcher; nothing gets killed. It only reads the window id in
  `/tmp/carplay_pi_launcher_winid`.
- **`launcher/launcher.py`** (+ `flappy.py`, `info.py`, `trip.py`,
  `logs.py`): the original pygame implementation. Not autostarted; kept as
  a manual fallback (tiles now laid out in two rows so all five fit the
  800px screen): SSH in, `pkill -9 -f chromium` and `pkill -9 -f
  server.py`, then `python3 /home/ajxd2/launcher/launcher.py` by hand.
  `flappy.py` is still what the new launcher's Flappy tile runs.
- **Phones view** (backed by `launcher/dongle.py`): lists the dongle's
  paired phones and forgets them, plus a live dongle CPU/temp/mem line. It
  talks to the dongle's web panel (`http://192.168.43.1/cgi-bin/server.cgi`)
  since the USB protocol can't edit the paired list. That panel is only
  reachable over the dongle's Wi-Fi AP, so opening the view **borrows
  `wlan0`** to join `AutoKit-8169`, and leaving it hands `wlan0` back via
  `wpa_cli reconfigure`. A generation counter makes sure a join that's
  still in flight when you leave hands `wlan0` back instead of parking it
  on the dongle's AP, and server startup does the same if a previous run
  died mid-view. Using this view interrupts an SSH-over-`wlan0` session
  (use `eth0`). `launcher/tools/ccpa_panel.py` is the standalone CLI
  equivalent (with working `--proxy socks5h://` support for an `ssh -D`
  tunnel).

### The bug that ate most of a session: the old autostart loop

The original `~/.config/openbox/autostart` launched CarPlay directly:
`(while true; do react-carplay.AppImage; sleep 2; done) &`. Every time
the launcher (or a manual `pkill`) killed CarPlay to hide/replace it,
this loop would silently relaunch it 2 seconds later, fighting with the
launcher's own process tracking. This produced duplicate CarPlay
instances and what looked like random glitches for a long time before
being traced to the loop itself via `pstree`, not a bug in the launcher
code. **`launcher/deploy.sh` removes that loop line** as part of
deploying. If you ever hand-restore the old autostart line for some
reason, the launcher's process management will fight it again.

### Known limitations

- If `server.py` restarts (crash, redeploy), it can't re-attach to apps
  the previous run started, so it kills them on startup and starts clean;
  with auto-launch on, CarPlay comes straight back. Expect a few seconds of
  CarPlay reconnecting whenever the server restarts.
- Killing Chromium's process tree with `pkill -9 -f chromium` reliably
  drops the *current* SSH session for a couple of seconds (looks like a
  brief system-wide hiccup, maybe GPU/DRM cleanup on this Pi) even though
  the device itself is fine -- `deploy.sh` runs that kill as its own,
  last, `ssh` call for exactly this reason. If you're ever scripting
  something similar by hand, don't chain other cleanup commands after it
  in the same remote shell; they won't run.

- `launcher/deploy.sh [--autostart] [user@host]`: same `/media/root-ro`
  write-through pattern as `pi-monitor/deploy.sh`. Copies the launcher as
  one `tar` stream with `--overwrite` (files are rewritten in place: tar's
  default of replacing them with new inodes leaves the running overlay
  serving the old cached copies until reboot), installs `~/.asoundrc`, runs
  the idempotent react-carplay audio patch, then restarts the stack. If the
  autostart respawn loop is running it only kills the stack and lets the
  loop bring `server.py` back, never starting a second copy by hand. By
  default it **doesn't touch the openbox autostart file**; pass
  `--autostart` (after verifying on the real touchscreen) to install the
  launcher block and point the startup `amixer` lines at the USB adapter by
  name. Also installs the `chromium` apt package persistently if missing.

## Audio

(Planned: the carrier board in `hardware/carrier/` replaces the USB
adapter with I2S straight into a 4-channel amp. The Pi then runs at a
fixed 48 kHz as I2S clock consumer; details in
[hardware/carrier/README.md](hardware/carrier/README.md) and
[launcher/board/README.md](launcher/board/README.md). Everything below
describes the current USB setup.)

Everything CarPlay plays (music, calls, Siri, navigation) arrives from the
phone over Wi-Fi to the dongle, then over USB to react-carplay, which plays
it through PulseAudio to the Unitek USB adapter (`card "Device"`). The mic
goes the other way: USB adapter -> PulseAudio -> react-carplay
(`getUserMedia`, 16 kHz mono) -> dongle -> phone, only while the phone asks
for it (`starting mic` / `stopping mic` in `/tmp/carplay.log`).

Fixes applied, and why:

- **Crackling: react-carplay's audio player had no jitter buffer.** Its
  AudioWorklet started playing the moment 128 frames (~3 ms) existed and
  went silent for a render quantum whenever the next packet was slightly
  late, which wireless CarPlay makes constant (20-35 `UNDERFLOW`s a minute
  in the log). `launcher/tools/patch_carplay_audio.py` extracts the
  AppImage once to `~/react-carplay` and swaps in
  `tools/carplay_audio_worklet.js`: it waits for 120 ms of audio before
  (re)starting, and if the buffer's *minimum* over 3 s stays 60 ms above
  that (slow clock drift, not a burst), drops the excess once so latency
  can't creep up on a long drive. Same-size in-place edit of `app.asar`,
  SHA-256-checked, idempotent, run by `deploy.sh`. `server.py` runs
  `~/react-carplay/AppRun` (with `APPDIR` set; `AppRun` can't find itself
  without it) and falls back to the stock AppImage if it's missing. Result:
  zero underflows in the same listening test. The original AppImage is
  untouched.
- **Mic dead on phone calls: dongle `CallQuality` was HD.** Set to Norm
  (0). See the dongle panel section.
- **react-carplay `mediaDelay` 300 -> 1000** (in
  `~/.config/react-carplay/config.json`, persisted): the dongle-side jitter
  buffer, which react-carplay pushes to the dongle on every connect. 300
  was the minimum; 1000 is the panel's default.
- **PulseAudio buffer**: `/etc/pulse/daemon.conf` had
  `default-fragment-size-msec = 15` with `tsched=0` in `default.pa` (about
  60 ms of buffer). Now 25 ms x `default-fragments = 8` (~200 ms), still
  `tsched=0`. Persisted to `/media/root-ro/etc/pulse/daemon.conf`.
- **`~/.asoundrc`** (repo: `launcher/system/asoundrc`) routes plain-ALSA
  programs through PulseAudio. The old one pinned `defaults.pcm.card 1`,
  but card numbers move between boots (1 is now HDMI, no capture) and
  those defaults only accept an index. Autostart's `amixer` lines use
  `-c Device` (the adapter's name) for the same reason.
- CarPlay's `height` in its config stays at **640** (react-carplay's
  default). 480 looked right until the window was hidden and shown again,
  after which CarPlay's page grew scrollbars.

## Runtime state that survives reboot

The launcher persists state through `launcher/persist.py`
(`write_through()`: remount `/media/root-ro` rw, write a temp file, sync,
rename, best-effort remount ro):

- `launcher/config.json` (startup app) and `launcher/trip_state.json`
  (Trip Calc values): written on change.
- `launcher/volume.json`: PulseAudio's own restore database lives on the
  tmpfs overlay and autostart forces 100% at boot, so `server.py` restores
  the saved level on startup and saves it once a change has held for ~4 s,
  whatever changed it.
- `~/.config/react-carplay/config.json`: react-carplay writes this itself
  when you change its settings; a watcher thread notices (every 3 s, only
  complete JSON) and persists it.

## Clock (no RTC)

The Pi 4 has no real-time clock and no `fake-hwclock` here, so every boot
starts at whatever time the image last held (currently Mar 31) until
`systemd-timesyncd` syncs over the network, which in the car may never
happen. The launcher shows `--:--` / "Clock not set" until
`timedatectl` reports `NTPSynchronized=yes`; CarPlay's own status bar
always shows the phone's time. Real fix: a DS3231 RTC plus
`dtoverlay=i2c-rtc,ds3231` in `/boot/firmware/config.txt`, seeded once
with `sudo hwclock -w` while online. The carrier board
(`hardware/carrier/`) has one on board with a CR2032, so this goes away
once it is installed.

## Security notes

- react-carplay listens on **`0.0.0.0:4000`** (socket.io) with no auth,
  reachable from any network the Pi joins. There's no firewall. A
  persistent nftables ruleset (allow `lo`, established, 22; drop the rest)
  would close it; test it carefully, since a mistake can lock out SSH.
- SSH is pubkey-only; the launcher API binds to `127.0.0.1`.

## pi-monitor: temp/network notifications

`pi-monitor/` in this repo is a small on-screen alert system, since the
CarPlay app runs fullscreen with no window chrome:

- `pi-monitor/pi-monitor.sh`: polls every 10s, pops up a `dunst`
  notification (via `notify-send`) when CPU temp crosses 70°C (warn) /
  80°C (critical). Warnings re-alert every 5 min while sustained.
  Critical alerts re-alert every 1 min and also play an audible beep,
  since a red border alone isn't urgent enough to notice while driving.
  Clears with a confirmation notification when temp drops back down.
  Also pops up the IP address the moment `eth0` gets a link with an
  address.
- The critical beep (`pi-monitor/assets/critical-beep.wav`) fully mutes
  the CarPlay audio sink-input before playing and unmutes it right
  after (see `play_critical_alert` in `pi-monitor.sh`), rather than just
  ducking the volume. A partial duck still let the beep get lost in the
  music; full mute is what actually interrupts. The beep itself is a
  synthesized square wave (harsher/more harmonics than a sine, reads as
  sharper), not a stock desktop sound, played at 150% gain via
  `paplay --volume`. Regenerate it with:
  ```sh
  ffmpeg -y -f lavfi -i "aevalsrc=exprs='0.9*(2*gt(sin(2*PI*1500*t)\,0)-1)':s=44100:d=0.15,afade=t=in:d=0.005,afade=t=out:st=0.145:d=0.005" \
    -f lavfi -i "anullsrc=r=44100:cl=stereo:d=0.5" \
    -f lavfi -i "aevalsrc=exprs='0.9*(2*gt(sin(2*PI*1500*t)\,0)-1)':s=44100:d=0.15,afade=t=in:d=0.005,afade=t=out:st=0.145:d=0.005" \
    -filter_complex "[0:a]pan=stereo|c0=c0|c1=c0[b1];[2:a]pan=stereo|c0=c0|c1=c0[b2];[b1][1:a][b2]concat=n=3:v=0:a=1[out]" \
    -map "[out]" -ar 44100 -ac 2 -acodec pcm_s16le pi-monitor/assets/critical-beep.wav
  ```
  (two 150ms beeps at 1500Hz with a 0.5s gap between them)
- Installed persistently: `dunst` and `libnotify-bin` via
  `overlayroot-chroot`. Script and beep asset live at
  `~/pi-monitor/` on the Pi, both dunst and the monitor started from a
  marked block appended to `~/.config/openbox/autostart`.
- `pi-monitor/dunstrc`: the "Refined Card" style (see `pi-monitor/styles/`
  for the 6 variants that were tried and rejected/kept for reference).
  Dark, muted, desaturated frame color as the accent (slate-blue for
  normal, brick-red for critical) rather than a bright saturated color,
  since the brighter Modern Card variant read as too playful. Popups
  appear top-center (`origin = top-center`) with a real colored icon
  per notification (`pi-monitor/assets/icons/info.png` for
  connectivity/info, `warning.png` for thermal warn/critical), rather
  than relying on text glyphs. The icons are hand-authored SVGs
  (`assets/icons/*.svg`, rendered to PNG via `rsvg-convert`), not the
  system's Adwaita symbolic icons: those render in a dark near-black
  fill meant to be recolored by GTK's CSS icon theming, which doesn't
  happen when dunst loads them standalone, so they'd be invisible on a
  dark background. Deployed to `~/.config/dunst/dunstrc` on the Pi.
  Notifications appear instantly (no slide-in animation): dunst has no
  built-in animation system, and its windows are override-redirect,
  which compositors (including the `picom` running here) often exclude
  from effects by design. Untested and left alone rather than sinking
  time into an uncertain experiment.
- `pi-monitor/deploy.sh [user@host]`: the actual devex fix. Edit
  `pi-monitor.sh` here, run `./deploy.sh`, and it:
  1. remounts `/media/root-ro` rw on the Pi
  2. copies the script, assets (beep + icons), and dunstrc there (persists across
     reboot)
  3. ensures the autostart block exists (idempotent, won't duplicate)
  4. best-effort remounts back to `ro`
  5. kills and relaunches the live `dunst`/`pi-monitor.sh` processes on
     the running session so you see the change immediately, without
     waiting for a reboot

  No SD card pulling required for iterating on this script. (Remember
  the "new packages need a reboot to appear live" caveat above if you
  ever add a dependency via `apt`.)

## Quick reference

| Task | Command |
|---|---|
| SSH in | `ssh ajxd2@raspi.local` |
| Check temp | `cat /sys/class/thermal/thermal_zone0/temp` (millidegrees C) or `vcgencmd measure_temp` |
| Check IP | `ip -4 -br addr show eth0` |
| Make root writable (this boot only) | `sudo mount -o remount,rw /media/root-ro` |
| Install a package persistently | `sudo overlayroot-chroot apt-get install -y <pkg>` |
| Deploy pi-monitor changes | `cd pi-monitor && ./deploy.sh` |
| Deploy launcher changes | `cd launcher && ./deploy.sh` |
| Launcher / CarPlay logs | `/tmp/server_startup.log`, `/tmp/carplay.log` (or the Logs view) |
| Dongle settings | `python3 launcher/tools/ccpa_panel.py infos` (on the AutoKit Wi-Fi) |
| Re-apply the CarPlay audio patch | `sudo python3 ~/launcher/tools/patch_carplay_audio.py` |
| Frontend dev server | `cd launcher && python3 server.py --dev` |
| Fully reset the overlay / pick up new packages | `sudo reboot` |

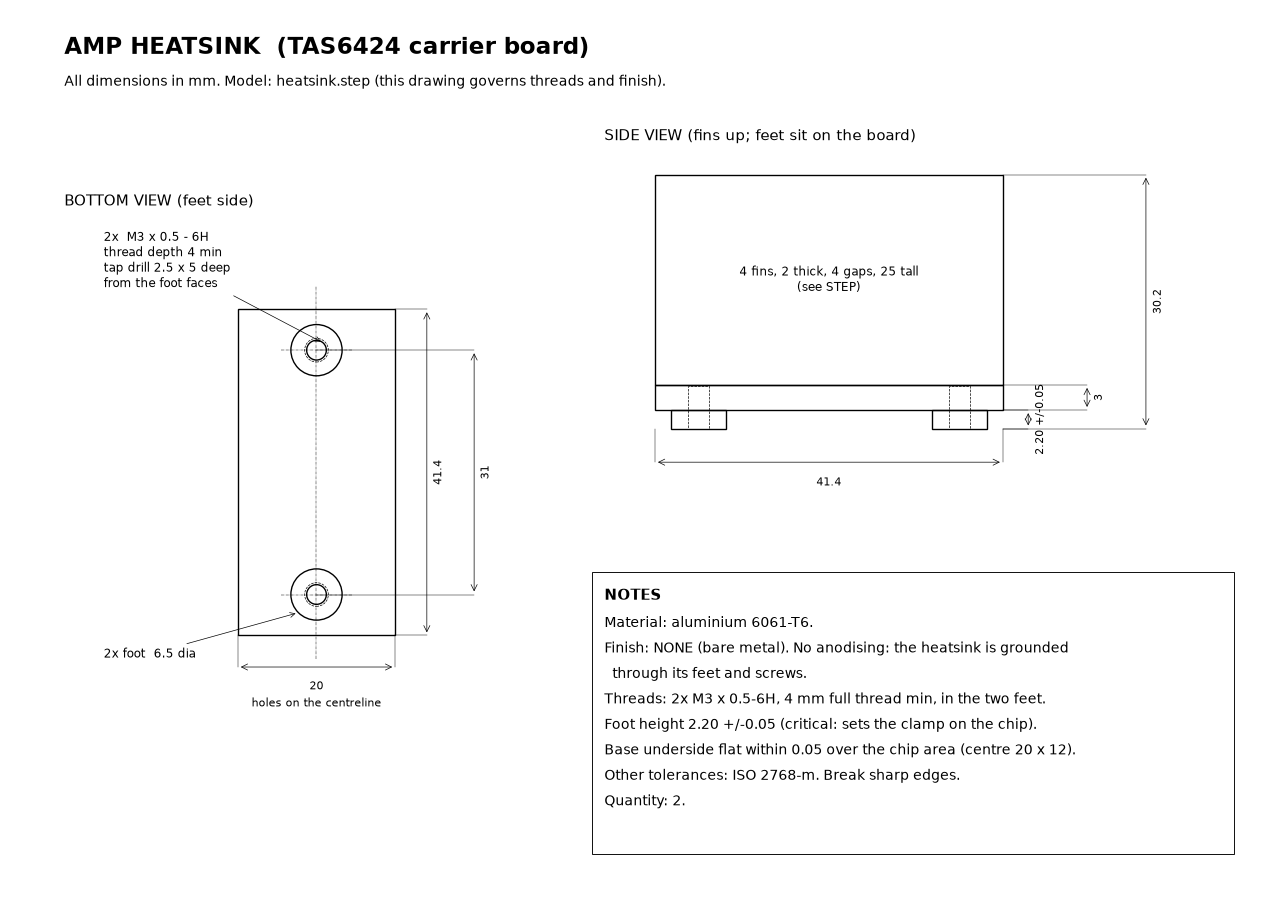
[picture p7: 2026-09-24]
hardware/carrier/mech/heatsink_drawing.png

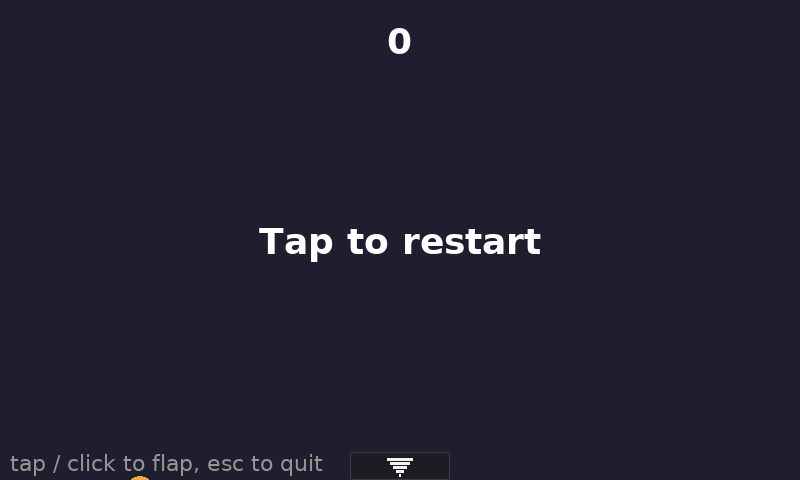
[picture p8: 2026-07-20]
docs/screenshots/flappy-bird.png

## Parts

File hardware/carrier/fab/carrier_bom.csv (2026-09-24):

Comment | Designator | Footprint | LCSC | MPN | Manufacturer | Qty | DNP
CR2032 | BT1 | Battery:BatteryHolder_MYOUNG_BS-07-A1BJ001_CR2032 | C2979167 | BS-07-A1BJ001 | MYOUNG | 1
100nF | C1,C2,C4 | Capacitor_SMD:C_0805_2012Metric | C28233 | CL21B104KCFNNNE | Samsung Electro-Mechanics | 3
22nF | C3 | Capacitor_SMD:C_0805_2012Metric | C1729 | CL21B223KBANNNC | Samsung Electro-Mechanics | 1
220nF | C5 | Capacitor_SMD:C_0603_1608Metric | C64705 | CL10B224KB8NNNC | Samsung Electro-Mechanics | 1
100nF | C6,C7,C9,C10,C11,C13,C14,C15,C18,C19,C22,C26,C29,C31,C33,C67,C69,C71 | Capacitor_SMD:C_0603_1608Metric | C14663 | CC0603KRX7R9BB104 | YAGEO | 18
10nF | C8 | Capacitor_SMD:C_0603_1608Metric | C57112 | 0603B103K500NT | FH | 1
47uF | C12,C24,C25 | Capacitor_SMD:C_1210_3225Metric | C90142 | TMK325ABJ476MM-P | Taiyo Yuden | 3
10uF | C16,C17,C30,C32,C34 | Capacitor_SMD:C_1206_3216Metric | C89632 | CL31B106KBHNNNE | Samsung Electro-Mechanics | 5
1uF | C20,C21,C27,C28,C37,C38,C39,C40,C43,C44,C45,C46,C47,C48,C49,C50,C74 | Capacitor_SMD:C_0603_1608Metric | C5199872 | CL10B105KB8NQNC | Samsung Electro-Mechanics | 17
22pF | C23 | Capacitor_SMD:C_0603_1608Metric | C1653 | CL10C220JB8NNNC | Samsung Electro-Mechanics | 1
1uF | C35,C51,C53,C55,C57,C59,C61,C63,C65 | Capacitor_SMD:C_0805_2012Metric | C28323 | CL21B105KBFNNNE | Samsung Electro-Mechanics | 9
470uF | C36 | Capacitor_SMD:CP_Elec_10x12.5 | C55348714 | KAT1H471M10130PDT | KNSCHA | 1
2.2uF | C41,C42 | Capacitor_SMD:C_0805_2012Metric | C77081 | GRM21BR71E225KE11L | Murata | 2
1nF | C52,C54,C56,C58,C60,C62,C64,C66,C75 | Capacitor_SMD:C_0603_1608Metric | C163508 | CL10C102JB8NNNC | Samsung Electro-Mechanics | 9
10uF | C68,C70,C72,C73 | Capacitor_SMD:C_0805_2012Metric | C15850 | CL21A106KAYNNNE | Samsung Electro-Mechanics | 4
SMBJ33CA | D1 | Diode_SMD:D_SMB | C19077587 | SMBJ33CA | hongjiacheng | 1
H15VND3B | D2,D3,D7 | Diode_SMD:D_SOD-323 | C20615813 | H15VND3B | hongjiacheng | 3
1N4148W | D4,D5 | Diode_SMD:D_SOD-123 | C81598 | 1N4148W | ST(Semtech) | 2
BZT52C15 | D6 | Diode_SMD:D_SOD-123 | C19077412 | BZT52C15 | hongjiacheng | 1
RED | D8,D9,D10 | LED_SMD:LED_0603_1608Metric | C2286 | KT-0603R | Hubei KENTO Elec | 3
Harness_4Runner | J1 | Connector_Molex:Molex_Micro-Fit_3.0_43045-2012_2x10_P3.00mm_Vertical | C485575 | 430452012 | Molex | 1
Pi 4 GPIO | J2 | Connector_PinSocket_2.54mm:PinSocket_2x20_P2.54mm_Vertical | C7499354 | ZX-PM2.54-2-20PY | Megastar | 1
MIC | J4 | Connector_Audio:Jack_3.5mm_PJ320D_Horizontal | C431535 | PJ-320D | SHOU HAN | 1
4.7uH | L1 | Inductor_SMD:L_APV_APH0840 | C54123781 | APH0840T4R7MP | APV | 1
3.3uH | L2,L3,L4,L5,L6,L7,L8,L9 | Inductor_SMD:L_Chilisin_BMRx00060630 | C108294 | MHCI06030-3R3M-R8 | Chilisin | 8
FAN1/FAN2 | M1,M2 | Connector:FanPinHeader_1x04_P2.54mm_Vertical | C240840 | 470531000 | Molex | 2
BUK7Y4R8-60E | Q1,Q2 | Package_TO_SOT_SMD:LFPAK56 | C503619 | BUK7Y4R8-60EX | Nexperia | 2
MMBT3904 | Q3,Q4,Q5 | Package_TO_SOT_SMD:SOT-23 | C20526 | MMBT3904 | Changjing | 3
2N7002 | Q6,Q7 | Package_TO_SOT_SMD:SOT-23 | C8545 | 2N7002 | Changjing | 2
100R | R1 | Resistor_SMD:R_0603_1608Metric | C22775 | 0603WAF1000T5E | UNI-ROYAL | 1
95.3k | R2 | Resistor_SMD:R_0603_1608Metric | C2907078 | FRC0603F9532TS | FOJAN | 1
5.11k | R3 | Resistor_SMD:R_0603_1608Metric | C2933233 | FRC0603F5111TS | FOJAN | 1
3.65k | R4 | Resistor_SMD:R_0603_1608Metric | C2930089 | FRC0603F3651TS | FOJAN | 1
1k | R5,R7,R12,R16,R33,R43,R45,R46 | Resistor_SMD:R_0603_1608Metric | C21190 | 0603WAF1001T5E | UNI-ROYAL | 8
10k | R6,R8,R10,R11,R19,R20,R22,R23,R25,R26,R34,R36,R44 | Resistor_SMD:R_0603_1608Metric | C25804 | 0603WAF1002T5E | UNI-ROYAL | 13
0R | R9,R30 | Resistor_SMD:R_0603_1608Metric | C21189 | 0603WAF0000T5E | UNI-ROYAL | 2
3.9k | R13,R14 | Resistor_SMD:R_0603_1608Metric | C23018 | 0603WAF3901T5E | UNI-ROYAL | 2
47k | R15,R18,R21,R24 | Resistor_SMD:R_0603_1608Metric | C25819 | 0603WAF4702T5E | UNI-ROYAL | 4
100k | R17,R27,R31,R35,R37 | Resistor_SMD:R_0603_1608Metric | C25803 | 0603WAF1003T5E | UNI-ROYAL | 5
26.7k | R28 | Resistor_SMD:R_0603_1608Metric | C2930082 | FRC0603F2672TS | FOJAN | 1
33.2k | R29 | Resistor_SMD:R_0603_1608Metric | C2933200 | FRC0603F3322TS | FOJAN | 1
24.9k | R32 | Resistor_SMD:R_0603_1608Metric | C25962 | 0603WAF2492T5E | UNI-ROYAL | 1
33R | R38,R39,R40,R41 | Resistor_SMD:R_0603_1608Metric | C23140 | 0603WAF330JT5E | UNI-ROYAL | 4
2.2k | R42 | Resistor_SMD:R_0603_1608Metric | C4190 | 0603WAF2201T5E | UNI-ROYAL | 1
LM74800-Q1 | U1 | Package_SON:WSON-12-1EP_3x3mm_P0.5mm_EP1.5x2.5mm | C3215600 | LM74800QDRRRQ1 | Texas Instruments | 1
ADS1115IDGS | U2 | Package_SO:TSSOP-10_3x3mm_P0.5mm | C37593 | ADS1115IDGSR | Texas Instruments | 1
DS3231SN | U3 | Package_SO:SOIC-16W_7.5x10.3mm_P1.27mm | C9866 | DS3231SN#T&R | Analog Devices | 1
CAT24C32 | U4 | Package_SO:SOIC-8_3.9x4.9mm_P1.27mm | C81193 | CAT24C32WI-GT3 | onsemi | 1
LM61460-Q1 | U5 | carrier:TI_RJR0014A_VQFN-HR-14_3.5x4mm | C2876600 | LM61460AFSQRJRRQ1 | Texas Instruments | 1
TLV75533PDBV | U6 | Package_TO_SOT_SMD:SOT-23-5 | C404027 | TLV75533PDBVR | Texas Instruments | 1
TAS6424E-Q1 | U7 | Package_SO:SSOP-56_7.5x18.5mm_P0.635mm | C4991409 | TAS6424EQDKQRQ1 | Texas Instruments | 1
PCM1808-Q1 | U8 | Package_SO:TSSOP-14_4.4x5mm_P0.65mm | C2864157 | PCM1808QPWRQ1 | Texas Instruments | 1
12.288MHz | X1 | Oscillator:Oscillator_SMD_Abracon_ASE-4Pin_3.2x2.5mm | C7431335 | SX3M12.288B10F20TNN | SCTF | 1

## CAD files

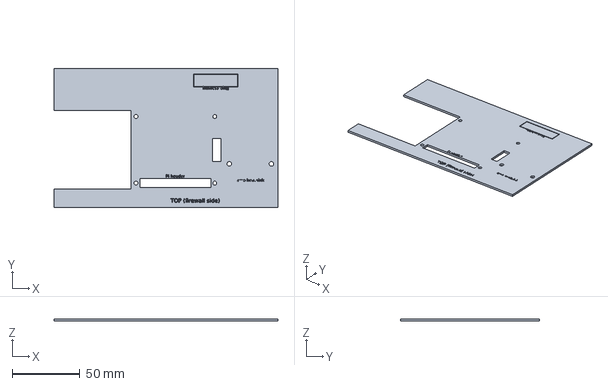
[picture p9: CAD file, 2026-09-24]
hardware/carrier/mech/fit_plate.step
164.9 x 102.0 x 1.60 mm

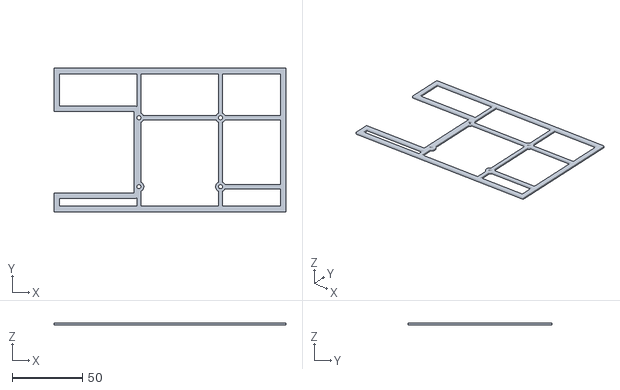
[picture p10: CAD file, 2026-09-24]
hardware/carrier/mech/fit_frame.stl
164.9 x 102.0 x 1.60

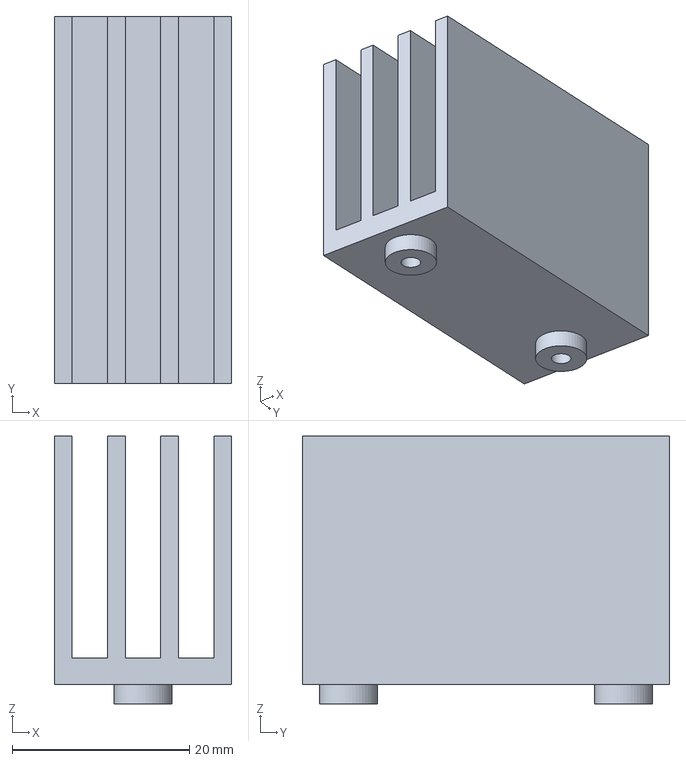
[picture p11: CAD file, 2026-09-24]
hardware/carrier/mech/heatsink.step
20.0 x 41.4 x 30.2 mm

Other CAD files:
hardware/carrier/mech/fit_plate.stl
hardware/carrier/mech/heatsink.stl

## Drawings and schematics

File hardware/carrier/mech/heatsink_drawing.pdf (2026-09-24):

# AMP HEATSINK (TAS6424 carrier board)

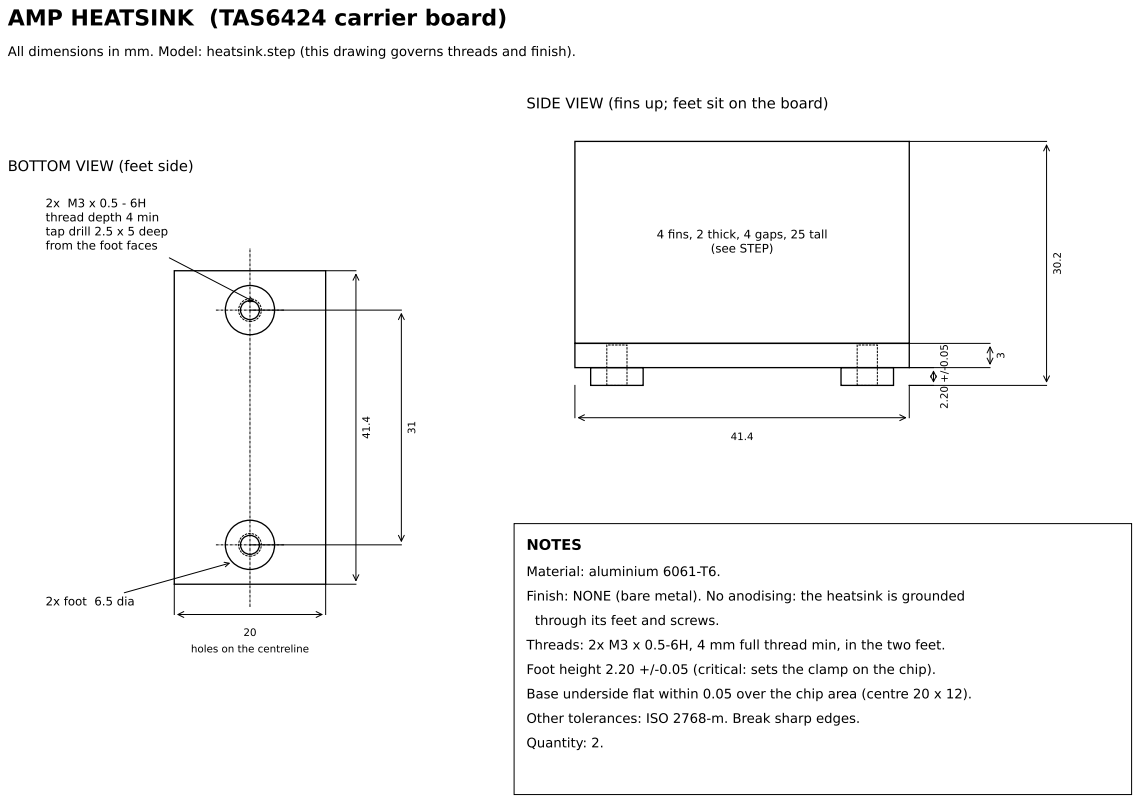
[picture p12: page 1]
2x foot 6.5 dia; (see STEP); NOTES; Material: aluminium 6061-T6.; Quantity: 2.

All dimensions in mm. Model: heatsink.step (this drawing governs threads and finish).

SIDE VIEW (fins up; feet sit on the board)

BOTTOM VIEW (feet side)

thread depth 4 min
tap drill 2.5 x 5 deep
from the foot faces

4 fins, 2 thick, 4 gaps, 25 tall

Finish: NONE (bare metal). No anodising: the heatsink is grounded

through its feet and screws.

holes on the centreline

Threads: 2x M3 x 0.5-6H, 4 mm full thread min, in the two feet.

Foot height 2.20 +/-0.05 (critical: sets the clamp on the chip).
Base underside flat within 0.05 over the chip area (centre 20 x 12).

Other tolerances: ISO 2768-m. Break sharp edges.

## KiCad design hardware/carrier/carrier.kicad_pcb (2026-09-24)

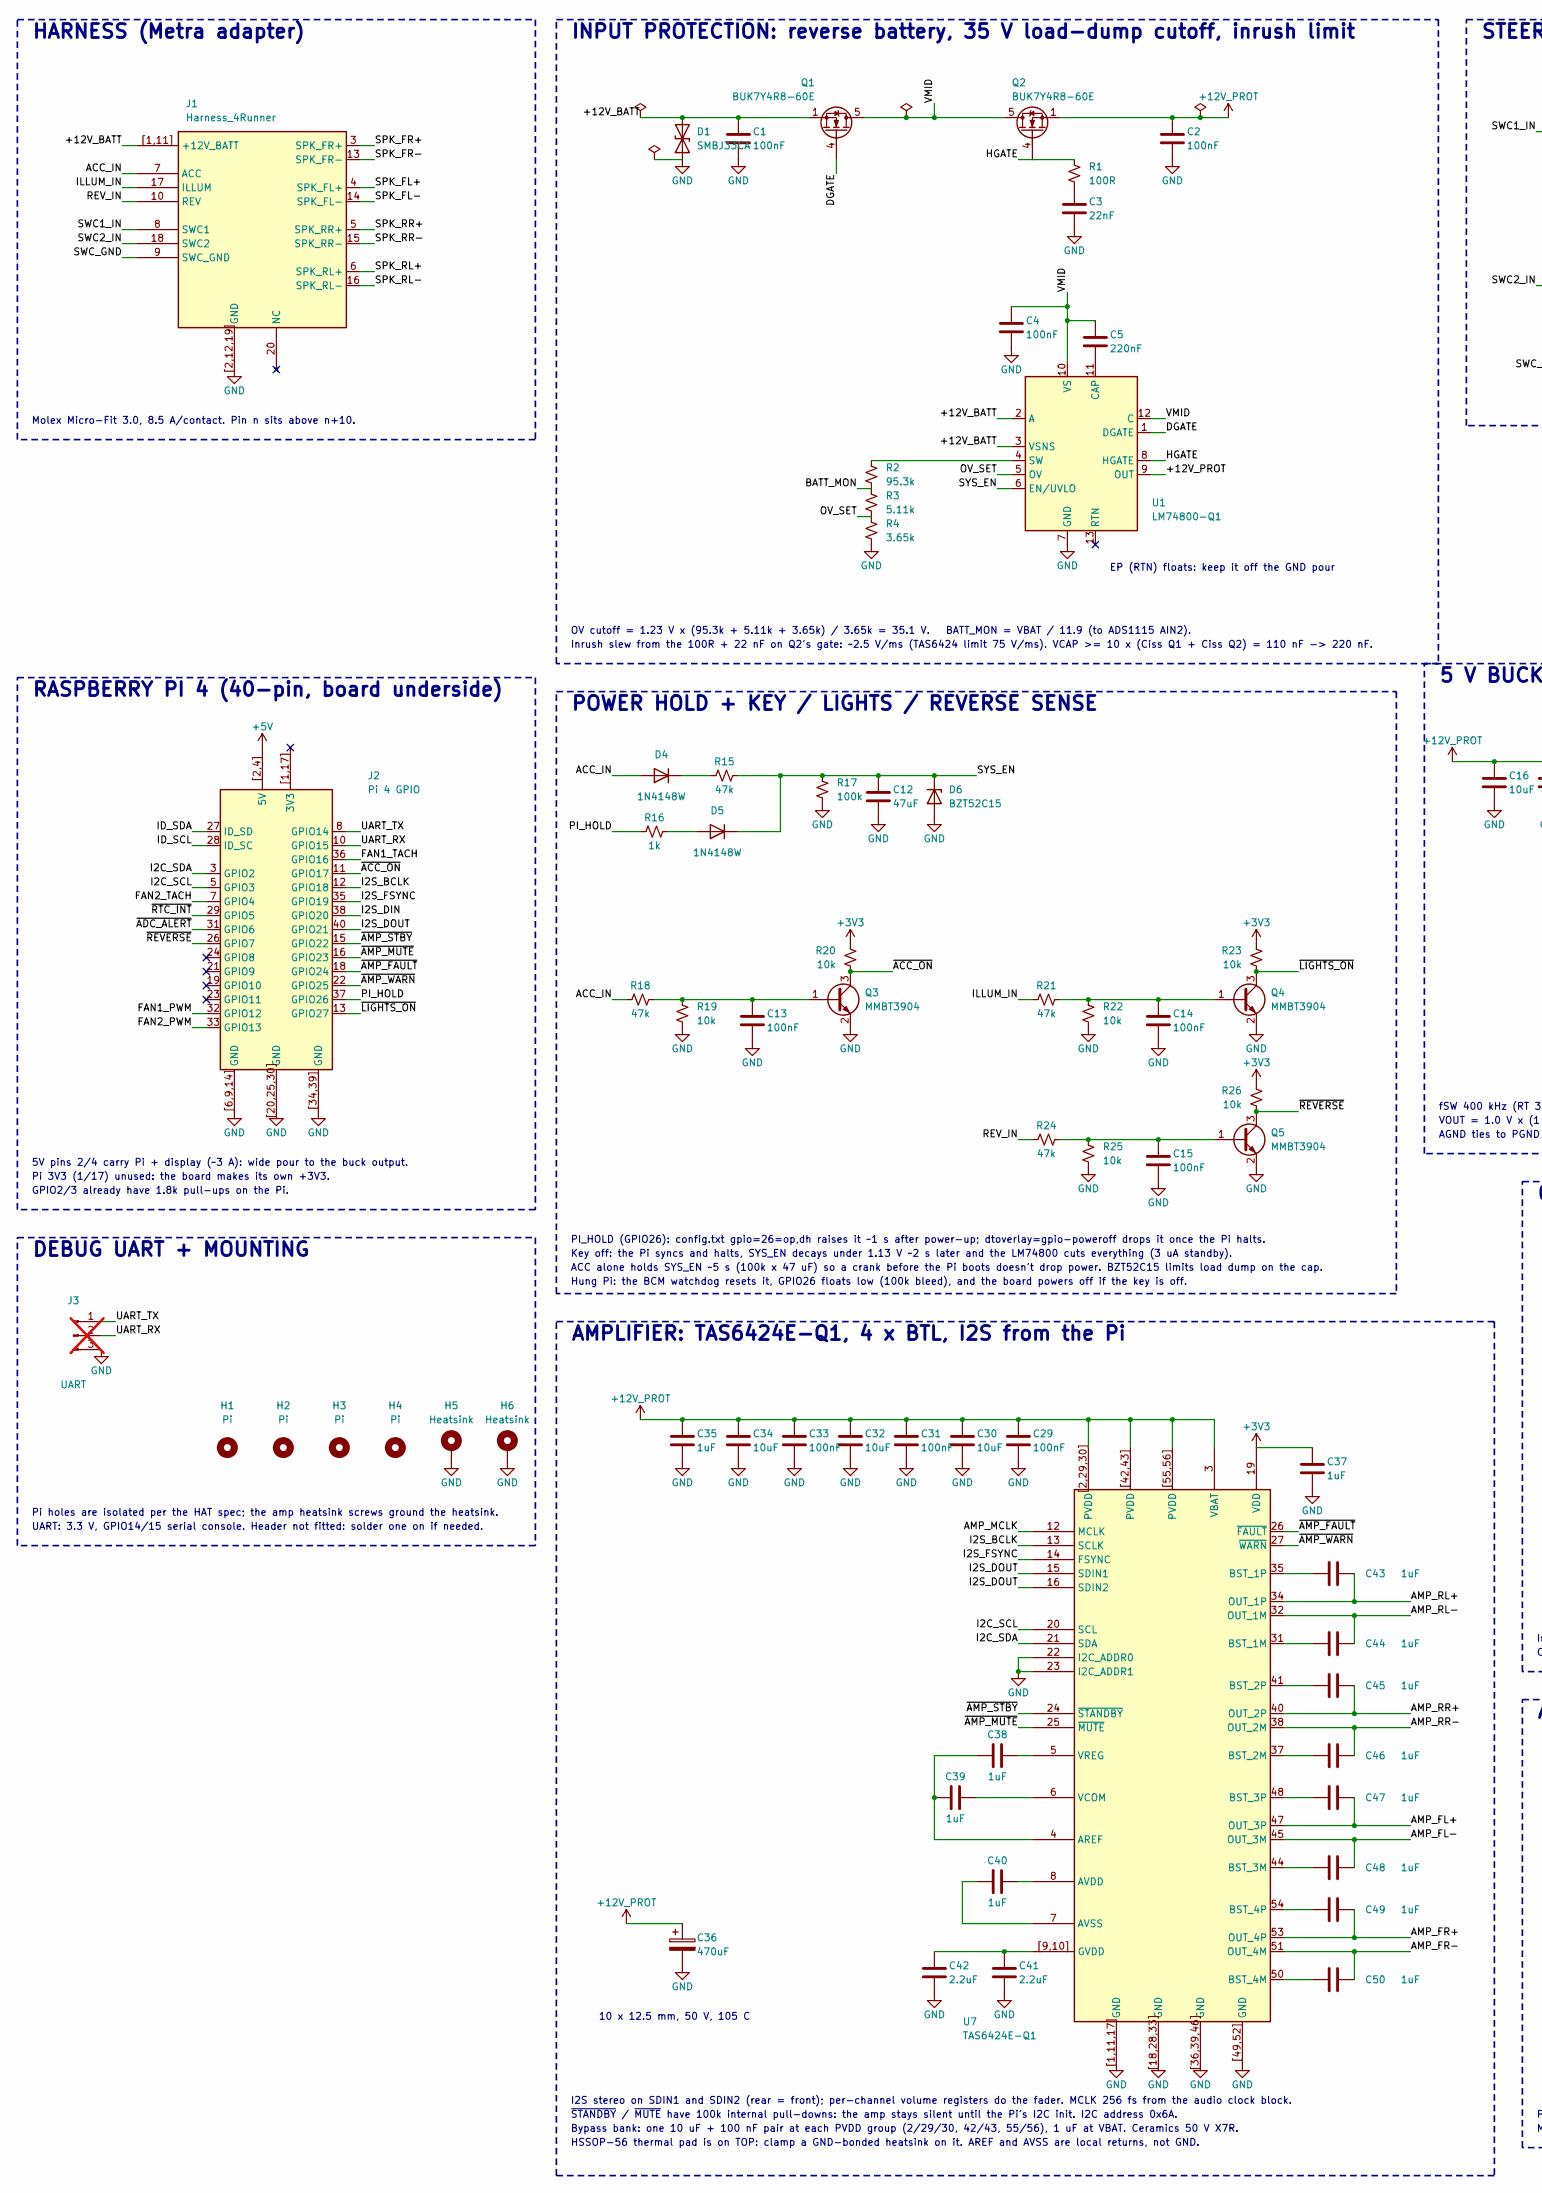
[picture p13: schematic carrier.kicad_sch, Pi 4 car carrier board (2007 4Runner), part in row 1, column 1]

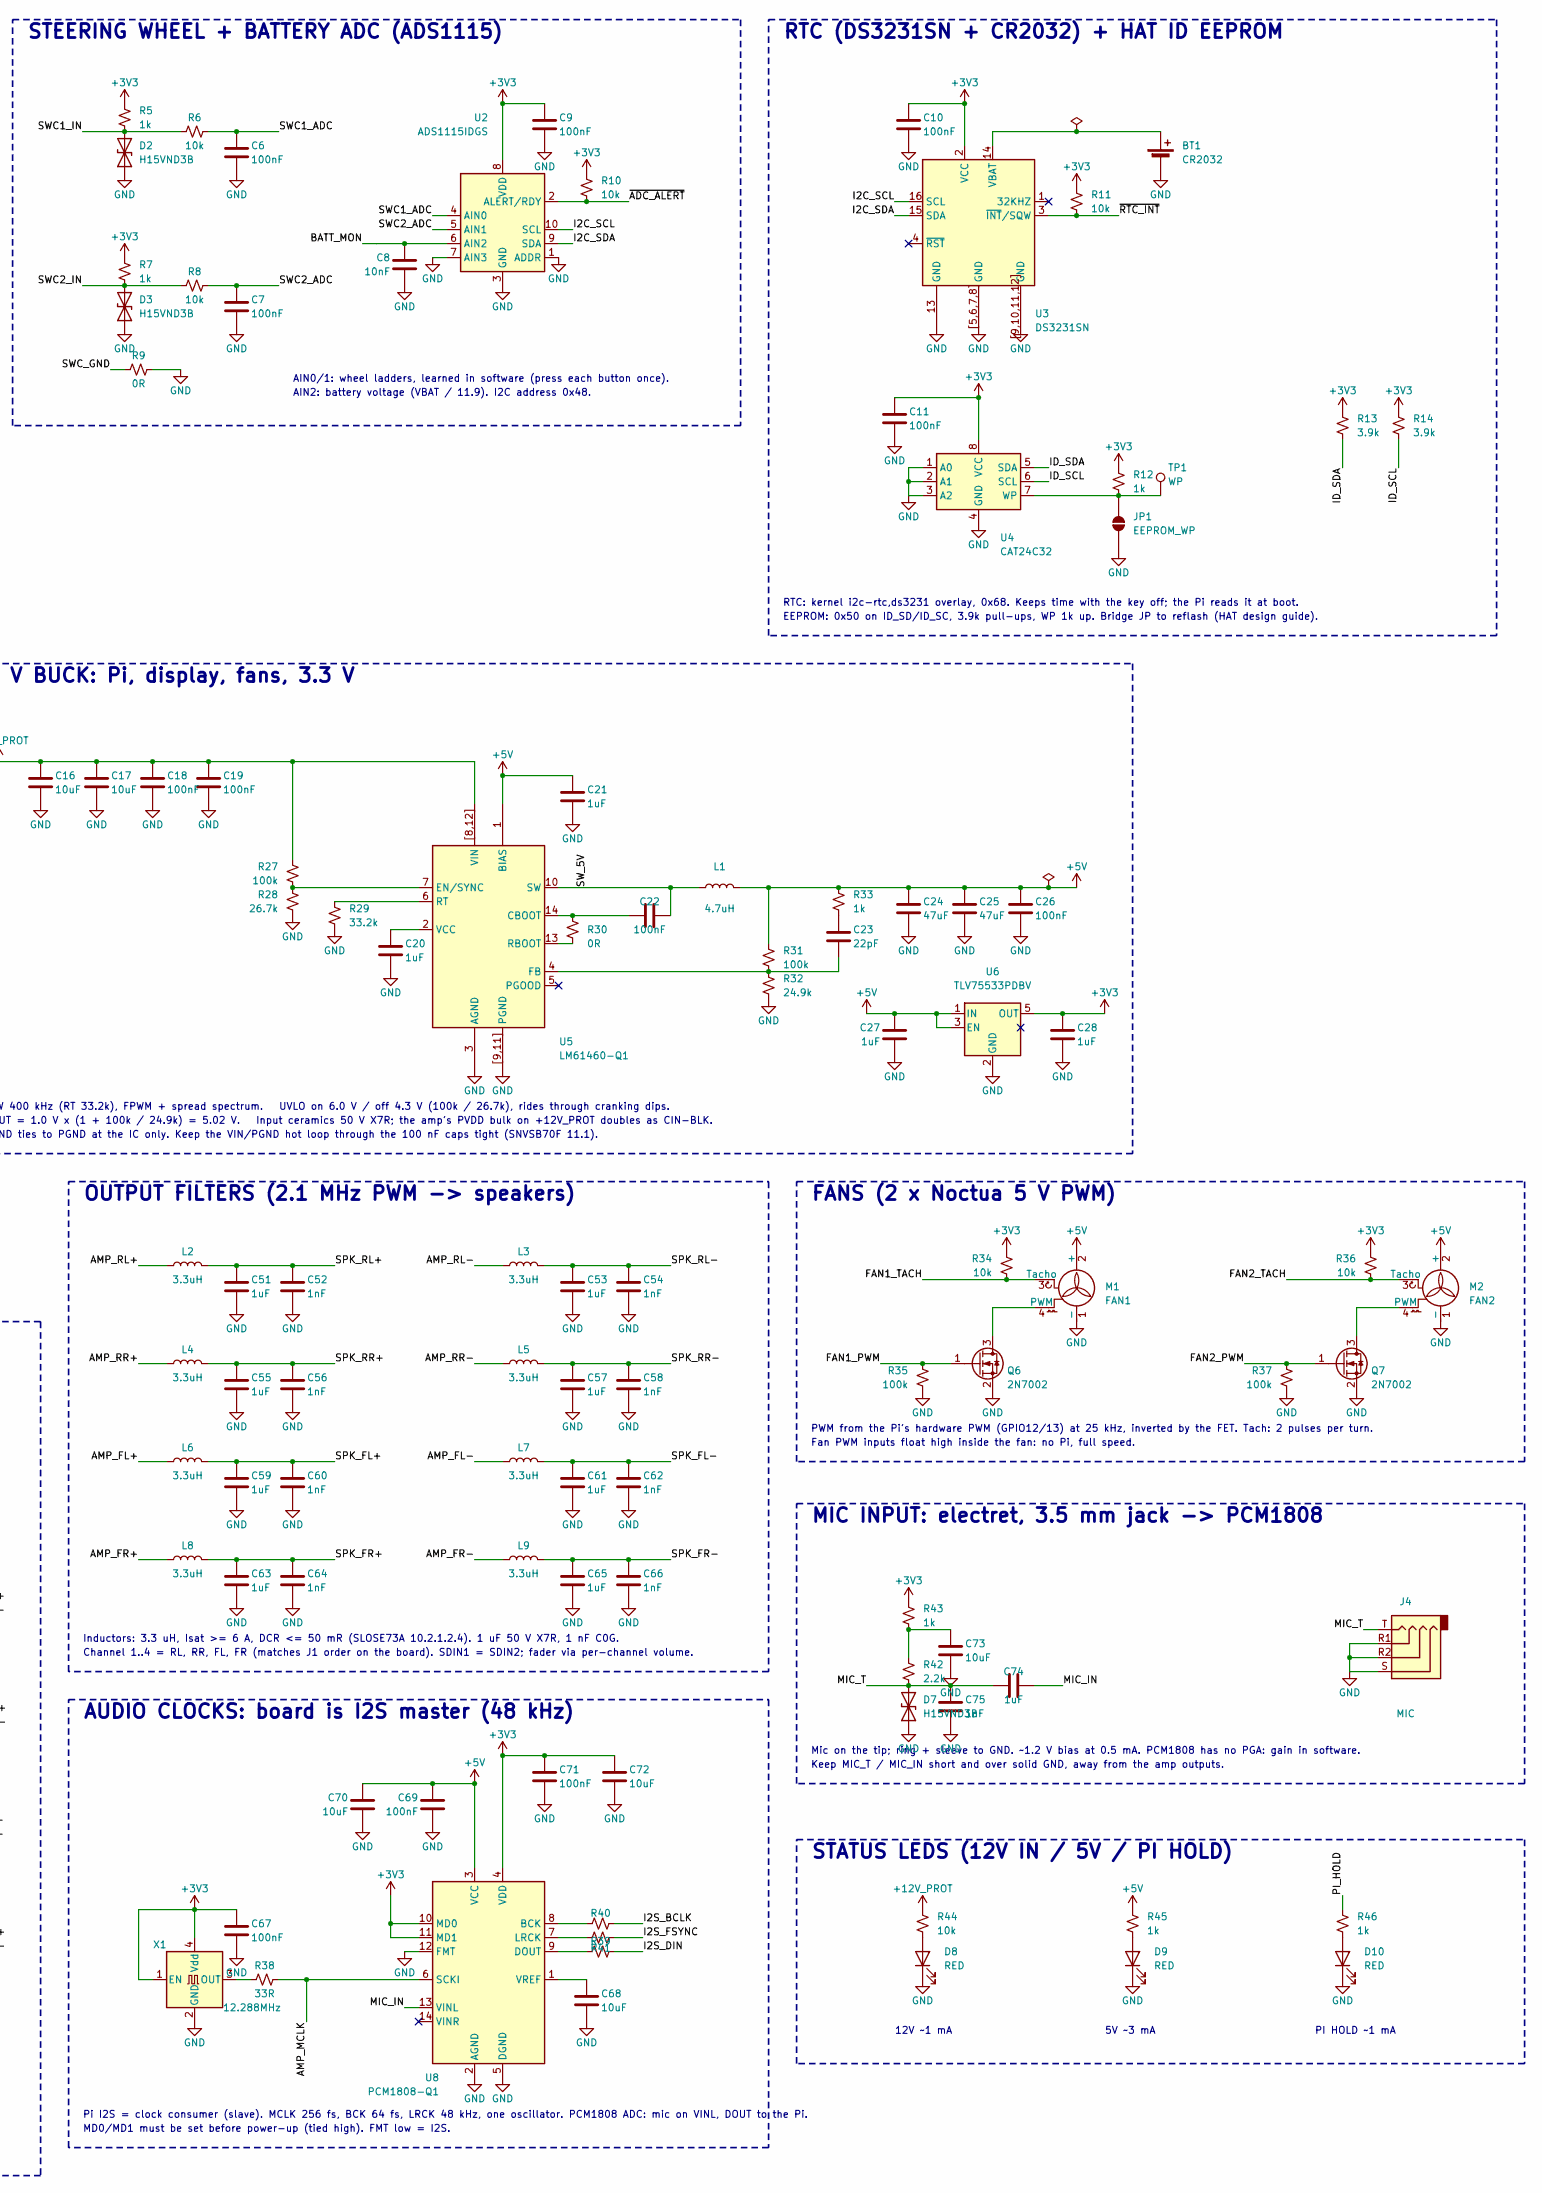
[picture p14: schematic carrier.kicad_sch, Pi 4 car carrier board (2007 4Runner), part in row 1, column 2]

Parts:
BT1: CR2032; BatteryHolder_MYOUNG_BS-07-A1BJ001_CR2032; MPN BS-07-A1BJ001; LCSC C2979167
C1, C2, C4: 100nF; C_0805_2012Metric; MPN CL21B104KCFNNNE; LCSC C28233
C3: 22nF; C_0805_2012Metric; MPN CL21B223KBANNNC; LCSC C1729
C5: 220nF; C_0603_1608Metric; MPN CL10B224KB8NNNC; LCSC C64705
C6, C7, C9, C10, C11, C13, C14, C15, C18, C19, C22, C26, C29, C31, C33, C67, C69, C71: 100nF; C_0603_1608Metric; MPN CC0603KRX7R9BB104; LCSC C14663
C8: 10nF; C_0603_1608Metric; MPN 0603B103K500NT; LCSC C57112
C12, C24, C25: 47uF; C_1210_3225Metric; MPN TMK325ABJ476MM-P; LCSC C90142
C16, C17, C30, C32, C34: 10uF; C_1206_3216Metric; MPN CL31B106KBHNNNE; LCSC C89632
C20, C21, C27, C28, C37, C38, C39, C40, C43, C44, C45, C46, C47, C48, C49, C50, C74: 1uF; C_0603_1608Metric; MPN CL10B105KB8NQNC; LCSC C5199872
C23: 22pF; C_0603_1608Metric; MPN CL10C220JB8NNNC; LCSC C1653
C35, C51, C53, C55, C57, C59, C61, C63, C65: 1uF; C_0805_2012Metric; MPN CL21B105KBFNNNE; LCSC C28323
C36: 470uF; CP_Elec_10x12.5; MPN KAT1H471M10130PDT; LCSC C55348714
C41, C42: 2.2uF; C_0805_2012Metric; MPN GRM21BR71E225KE11L; LCSC C77081
C52, C54, C56, C58, C60, C62, C64, C66, C75: 1nF; C_0603_1608Metric; MPN CL10C102JB8NNNC; LCSC C163508
C68, C70, C72, C73: 10uF; C_0805_2012Metric; MPN CL21A106KAYNNNE; LCSC C15850
D1: SMBJ33CA; D_SMB; MPN SMBJ33CA; LCSC C19077587
D2, D3, D7: H15VND3B; D_SOD-323; MPN H15VND3B; LCSC C20615813
D4, D5: 1N4148W; D_SOD-123; MPN 1N4148W; LCSC C81598
D6: BZT52C15; D_SOD-123; MPN BZT52C15; LCSC C19077412
D8, D9, D10: RED; LED_0603_1608Metric; MPN KT-0603R; LCSC C2286
H1, H2, H3, H4: Pi; MountingHole_2.7mm_M2.5
H5, H6: Heatsink; MountingHole_3.2mm_M3_Pad_Via
J1: Harness_4Runner; Molex_Micro-Fit_3.0_43045-2012_2x10_P3.00mm_Vertical; MPN 430452012; LCSC C485575
J2: Pi 4 GPIO; PinSocket_2x20_P2.54mm_Vertical; MPN ZX-PM2.54-2-20PY; LCSC C7499354
J3: UART; PinHeader_1x03_P2.54mm_Vertical; not fitted
J4: MIC; Jack_3.5mm_PJ320D_Horizontal; MPN PJ-320D; LCSC C431535
JP1: EEPROM_WP; SolderJumper-2_P1.3mm_Open_RoundedPad1.0x1.5mm
L1: 4.7uH; L_APV_APH0840; MPN APH0840T4R7MP; LCSC C54123781
L2, L3, L4, L5, L6, L7, L8, L9: 3.3uH; L_Chilisin_BMRx00060630; MPN MHCI06030-3R3M-R8; LCSC C108294
M1: FAN1; FanPinHeader_1x04_P2.54mm_Vertical; MPN 470531000; LCSC C240840
M2: FAN2; FanPinHeader_1x04_P2.54mm_Vertical; MPN 470531000; LCSC C240840
Q1, Q2: BUK7Y4R8-60E; LFPAK56; MPN BUK7Y4R8-60EX; LCSC C503619
Q3, Q4, Q5: MMBT3904; SOT-23; MPN MMBT3904; LCSC C20526
Q6, Q7: 2N7002; SOT-23; MPN 2N7002; LCSC C8545
R1: 100R; R_0603_1608Metric; MPN 0603WAF1000T5E; LCSC C22775
R2: 95.3k; R_0603_1608Metric; MPN FRC0603F9532TS; LCSC C2907078
R3: 5.11k; R_0603_1608Metric; MPN FRC0603F5111TS; LCSC C2933233
R4: 3.65k; R_0603_1608Metric; MPN FRC0603F3651TS; LCSC C2930089
R5, R7, R12, R16, R33, R43, R45, R46: 1k; R_0603_1608Metric; MPN 0603WAF1001T5E; LCSC C21190
R6, R8, R10, R11, R19, R20, R22, R23, R25, R26, R34, R36, R44: 10k; R_0603_1608Metric; MPN 0603WAF1002T5E; LCSC C25804
R9, R30: 0R; R_0603_1608Metric; MPN 0603WAF0000T5E; LCSC C21189
R13, R14: 3.9k; R_0603_1608Metric; MPN 0603WAF3901T5E; LCSC C23018
R15, R18, R21, R24: 47k; R_0603_1608Metric; MPN 0603WAF4702T5E; LCSC C25819
R17, R27, R31, R35, R37: 100k; R_0603_1608Metric; MPN 0603WAF1003T5E; LCSC C25803
R28: 26.7k; R_0603_1608Metric; MPN FRC0603F2672TS; LCSC C2930082
R29: 33.2k; R_0603_1608Metric; MPN FRC0603F3322TS; LCSC C2933200
R32: 24.9k; R_0603_1608Metric; MPN 0603WAF2492T5E; LCSC C25962
R38, R39, R40, R41: 33R; R_0603_1608Metric; MPN 0603WAF330JT5E; LCSC C23140
R42: 2.2k; R_0603_1608Metric; MPN 0603WAF2201T5E; LCSC C4190
TP1: WP; TestPoint_Pad_D1.5mm
U1: LM74800-Q1; WSON-12-1EP_3x3mm_P0.5mm_EP1.5x2.5mm; MPN LM74800QDRRRQ1; LCSC C3215600
U2: ADS1115IDGS; TSSOP-10_3x3mm_P0.5mm; MPN ADS1115IDGSR; LCSC C37593
U3: DS3231SN; SOIC-16W_7.5x10.3mm_P1.27mm; MPN DS3231SN#T&R; LCSC C9866
U4: CAT24C32; SOIC-8_3.9x4.9mm_P1.27mm; MPN CAT24C32WI-GT3; LCSC C81193
U5: LM61460-Q1; TI_RJR0014A_VQFN-HR-14_3.5x4mm; MPN LM61460AFSQRJRRQ1; LCSC C2876600
U6: TLV75533PDBV; SOT-23-5; MPN TLV75533PDBVR; LCSC C404027
U7: TAS6424E-Q1; SSOP-56_7.5x18.5mm_P0.635mm; MPN TAS6424EQDKQRQ1; LCSC C4991409
U8: PCM1808-Q1; TSSOP-14_4.4x5mm_P0.65mm; MPN PCM1808QPWRQ1; LCSC C2864157
X1: 12.288MHz; Oscillator_SMD_Abracon_ASE-4Pin_3.2x2.5mm; MPN SX3M12.288B10F20TNN; LCSC C7431335

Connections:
+3V3: C9.1, C10.1, C11.1, C28.1, C37.1, C67.1, C71.1, C72.1, R5.1, R7.1, R10.1, R11.1, R12.1, R13.1, R14.1, R20.1, R23.1, R26.1, R34.1, R36.1, R43.1, U2.8 (VDD), U3.2 (VCC), U4.8 (VCC), U6.5 (OUT), U7.19 (VDD), U8.4 (VDD), U8.10 (MD0), U8.11 (MD1), X1.1 (EN), X1.4 (Vdd)
+5V: C21.1, C24.1, C25.1, C26.1, C27.1, C69.1, C70.1, J2.2, J2.4, J2.[2,4] (5V), L1.2, M1.2 (+), M2.2 (+), R31.1, R33.1, R45.1, U5.1 (BIAS), U6.1 (IN), U6.3 (EN), U8.3 (VCC)
+12V_PROT: C2.1, C16.1, C17.1, C18.1, C19.1, C29.1, C30.1, C31.1, C32.1, C33.1, C34.1, C35.1, C36.1, Q2.1 (S), Q2.2 (S), Q2.3 (S), R27.1, R44.1, U1.9 (OUT), U5.8, U5.12, U5.[8,12] (VIN), U7.2, U7.3 (VBAT), U7.29, U7.30, U7.42, U7.43, U7.55, U7.56, U7.[2,29,30] (PVDD), U7.[42,43] (PVDD), U7.[55,56] (PVDD)
/+12V_BATT: C1.1, D1.2 (A2), J1.1, J1.11, J1.[1,11] (+12V_BATT), Q1.1 (S), Q1.2 (S), Q1.3 (S), U1.2 (A), U1.3 (VSNS)
/ACC_IN: D4.2 (A), J1.7 (ACC), R18.1
/AMP_FL+: C47.2, L6.1, U7.47 (OUT_3P)
/AMP_FL-: C48.2, L7.1, U7.45 (OUT_3M)
/AMP_FR+: C49.2, L8.1, U7.53 (OUT_4P)
/AMP_FR-: C50.2, L9.1, U7.51 (OUT_4M)
/AMP_MCLK: R38.2, U7.12 (MCLK), U8.6 (SCKI)
/AMP_RL+: C43.2, L2.1, U7.34 (OUT_1P)
/AMP_RL-: C44.2, L3.1, U7.32 (OUT_1M)
/AMP_RR+: C45.2, L4.1, U7.40 (OUT_2P)
/AMP_RR-: C46.2, L5.1, U7.38 (OUT_2M)
/BATT_MON: C8.1, R2.2, R3.1, U2.6 (AIN2)
/DGATE: Q1.4 (G), U1.1 (DGATE)
/FAN1_PWM: J2.32 (GPIO12), Q6.1 (G), R35.1
/FAN1_TACH: J2.36 (GPIO16), M1.3 (Tacho), R34.2
/FAN2_PWM: J2.33 (GPIO13), Q7.1 (G), R37.1
/FAN2_TACH: J2.7 (GPIO4), M2.3 (Tacho), R36.2
/HGATE: Q2.4 (G), R1.1, U1.8 (HGATE)
/I2C_SCL: J2.5 (GPIO3), U2.10 (SCL), U3.16 (SCL), U7.20 (SCL)
/I2C_SDA: J2.3 (GPIO2), U2.9 (SDA), U3.15 (SDA), U7.21 (SDA)
/I2S_BCLK: J2.12 (GPIO18), R40.2, U7.13 (SCLK)
/I2S_DIN: J2.38 (GPIO20), R39.2
/I2S_DOUT: J2.40 (GPIO21), U7.15 (SDIN1), U7.16 (SDIN2)
/I2S_FSYNC: J2.35 (GPIO19), R41.2, U7.14 (FSYNC)
/ID_SCL: J2.28 (ID_SC), R14.2, U4.6 (SCL)
/ID_SDA: J2.27 (ID_SD), R13.2, U4.5 (SDA)
/ILLUM_IN: J1.17 (ILLUM), R21.1
/MIC_IN: C74.2, U8.13 (VINL)
/MIC_T: C74.1, C75.1, D7.2 (A2), J4.T, R42.2
/OV_SET: R3.2, R4.1, U1.5 (OV)
/PI_HOLD: J2.37 (GPIO26), R16.1, R46.1
/REV_IN: J1.10 (REV), R24.1
/SPK_FL+: C59.1, C60.1, J1.4 (SPK_FL+), L6.2
/SPK_FL-: C61.1, C62.1, J1.14 (SPK_FL-), L7.2
/SPK_FR+: C63.1, C64.1, J1.3 (SPK_FR+), L8.2
/SPK_FR-: C65.1, C66.1, J1.13 (SPK_FR-), L9.2
/SPK_RL+: C51.1, C52.1, J1.6 (SPK_RL+), L2.2
/SPK_RL-: C53.1, C54.1, J1.16 (SPK_RL-), L3.2
/SPK_RR+: C55.1, C56.1, J1.5 (SPK_RR+), L4.2
/SPK_RR-: C57.1, C58.1, J1.15 (SPK_RR-), L5.2
/SWC1_ADC: C6.1, R6.2, U2.4 (AIN0)
/SWC1_IN: D2.2 (A2), J1.8 (SWC1), R5.2, R6.1
/SWC2_ADC: C7.1, R8.2, U2.5 (AIN1)
/SWC2_IN: D3.2 (A2), J1.18 (SWC2), R7.2, R8.1
/SWC_GND: J1.9 (SWC_GND), R9.1
/SW_5V: C22.2, L1.1, U5.10 (SW)
/SYS_EN: C12.1, D5.1 (K), D6.1 (K), R15.2, R17.1, U1.6 (EN/UVLO)
/UART_RX: J2.10 (GPIO15), J3.2
/UART_TX: J2.8 (GPIO14), J3.1
/VMID: C4.1, C5.1, Q1.5 (D), Q2.5 (D), U1.10 (VS), U1.12 (C)
/~ACC_ON: J2.11 (GPIO17), Q3.3 (C), R20.2
/~ADC_ALERT: J2.31 (GPIO6), R10.2, U2.2 (ALERT/RDY)
/~AMP_FAULT: J2.18 (GPIO24), U7.26 (~FAULT)
/~AMP_MUTE: J2.16 (GPIO23), U7.25 (~MUTE)
/~AMP_STBY: J2.15 (GPIO22), U7.24 (~STANDBY)
/~AMP_WARN: J2.22 (GPIO25), U7.27 (~WARN)
/~LIGHTS_ON: J2.13 (GPIO27), Q4.3 (C), R23.2
/~REVERSE: J2.26 (GPIO7), Q5.3 (C), R26.2
/~RTC_INT: J2.29 (GPIO5), R11.2, U3.3 (~INT/SQW)
GND: BT1.2 (-), C1.2, C2.2, C3.2, C4.2, C6.2, C7.2, C8.2, C9.2, C10.2, C11.2, C12.2, C13.2, C14.2, C15.2, C16.2, C17.2, C18.2, C19.2, C20.2, C21.2, C24.2, C25.2, C26.2, C27.2, C28.2, C29.2, C30.2, C31.2, C32.2, C33.2, C34.2, C35.2, C36.2, C37.2, C41.2, C42.2, C51.2, C52.2, C53.2, C54.2, C55.2, C56.2, C57.2, C58.2, C59.2, C60.2, C61.2, C62.2, C63.2, C64.2, C65.2, C66.2, C67.2, C68.2, C69.2, C70.2, C71.2, C72.2, C73.2, C75.2, D1.1 (A1), D2.1 (A1), D3.1 (A1), D6.2 (A), D7.1 (A1), D8.1 (K), D9.1 (K), D10.1 (K), H5.1, H6.1, J1.2, J1.12, J1.19, J1.[2,12,19] (GND), J2.6, J2.9, J2.14, J2.20, J2.25, J2.30, J2.34, J2.39, J2.[6,9,14] (GND), J2.[20,25,30] (GND), J2.[34,39] (GND), J3.3, J4.R1, J4.R2, J4.S, JP1.2 (B), M1.1 (-), M2.1 (-), Q3.2 (E), Q4.2 (E), Q5.2 (E), Q6.2 (S), Q7.2 (S), R4.2, R9.2, R17.2, R19.2, R22.2, R25.2, R28.2, R29.2, R32.2, R35.2, R37.2, U1.7 (GND), U2.1 (ADDR), U2.3 (GND), U2.7 (AIN3), U3.5, U3.6, U3.7, U3.8, U3.9, U3.10, U3.11, U3.12, U3.13 (GND), U3.[5,6,7,8] (GND), U3.[9,10,11,12] (GND), U4.1 (A0), U4.2 (A1), U4.3 (A2), U4.4 (GND), U5.3 (AGND), U5.9, U5.11, U5.[9,11] (PGND), U6.2 (GND), U7.1, U7.11, U7.17, U7.18, U7.22 (I2C_ADDR0), U7.23 (I2C_ADDR1), U7.28, U7.33, U7.36, U7.39, U7.46, U7.49, U7.52, U7.[1,11,17] (GND), U7.[18,28,33] (GND), U7.[36,39,46] (GND), U7.[49,52] (GND), U8.2 (AGND), U8.5 (DGND), U8.12 (FMT), X1.2 (GND)
unnamed: BT1.1 (+), U3.14 (VBAT)
unnamed: C3.1, R1.2
unnamed: C23.1, R33.2
unnamed: C73.1, R42.1, R43.2
unnamed: D4.1 (K), R15.1
unnamed: D5.2 (A), R16.2
unnamed: D8.2 (A), R44.2
unnamed: D9.2 (A), R45.2
unnamed: D10.2 (A), R46.2
unnamed: JP1.1 (A), R12.2, TP1.1, U4.7 (WP)
unnamed: M1.4 (PWM), Q6.3 (D)
unnamed: M2.4 (PWM), Q7.3 (D)
unnamed: C13.1, Q3.1 (B), R18.2, R19.1
unnamed: C14.1, Q4.1 (B), R21.2, R22.1
unnamed: C15.1, Q5.1 (B), R24.2, R25.1
unnamed: C5.2, U1.11 (CAP)
unnamed: R2.1, U1.4 (SW)
unnamed: C22.1, R30.1, U5.14 (CBOOT)
unnamed: R27.2, R28.1, U5.7 (EN/SYNC)
unnamed: C23.2, R31.2, R32.1, U5.4 (FB)
unnamed: R30.2, U5.13 (RBOOT)
unnamed: R29.1, U5.6 (RT)
unnamed: C20.1, U5.2 (VCC)
unnamed: C38.1, C39.1, U7.4 (AREF)
unnamed: C40.2, U7.8 (AVDD)
unnamed: C40.1, U7.7 (AVSS)
unnamed: C44.1, U7.31 (BST_1M)
unnamed: C43.1, U7.35 (BST_1P)
unnamed: C46.1, U7.37 (BST_2M)
unnamed: C45.1, U7.41 (BST_2P)
unnamed: C48.1, U7.44 (BST_3M)
unnamed: C47.1, U7.48 (BST_3P)
unnamed: C50.1, U7.50 (BST_4M)
unnamed: C49.1, U7.54 (BST_4P)
unnamed: C41.1, C42.1, U7.9, U7.10, U7.[9,10] (GVDD)
unnamed: C39.2, U7.6 (VCOM)
unnamed: C38.2, U7.5 (VREG)
unnamed: R40.1, U8.8 (BCK)
unnamed: R39.1, U8.9 (DOUT)
unnamed: R41.1, U8.7 (LRCK)
unnamed: C68.1, U8.1 (VREF)
unnamed: R38.1, X1.3 (OUT)

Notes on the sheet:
HARNESS (Metra adapter)
Molex Micro-Fit 3.0, 8.5 A/contact. Pin n sits above n+10.
INPUT PROTECTION: reverse battery, 35 V load-dump cutoff, inrush limit
EP (RTN) floats: keep it off the GND pour
OV cutoff = 1.23 V x (95.3k + 5.11k + 3.65k) / 3.65k = 35.1 V. BATT_MON = VBAT / 11.9 (to ADS1115 AIN2).
Inrush slew from the 100R + 22 nF on Q2's gate: ~2.5 V/ms (TAS6424 limit 75 V/ms). VCAP >= 10 x (Ciss Q1 + Ciss Q2) = 110 nF -> 220 nF.
STEERING WHEEL + BATTERY ADC (ADS1115)
AIN0/1: wheel ladders, learned in software (press each button once).
AIN2: battery voltage (VBAT / 11.9). I2C address 0x48.
RTC (DS3231SN + CR2032) + HAT ID EEPROM
RTC: kernel i2c-rtc,ds3231 overlay, 0x68. Keeps time with the key off; the Pi reads it at boot.
EEPROM: 0x50 on ID_SD/ID_SC, 3.9k pull-ups, WP 1k up. Bridge JP to reflash (HAT design guide).
RASPBERRY PI 4 (40-pin, board underside)
5V pins 2/4 carry Pi + display (~3 A): wide pour to the buck output.
Pi 3V3 (1/17) unused: the board makes its own +3V3.
GPIO2/3 already have 1.8k pull-ups on the Pi.
POWER HOLD + KEY / LIGHTS / REVERSE SENSE
PI_HOLD (GPIO26): config.txt gpio=26=op,dh raises it ~1 s after power-up; dtoverlay=gpio-poweroff drops it once the Pi halts.
Key off: the Pi syncs and halts, SYS_EN decays under 1.13 V ~2 s later and the LM74800 cuts everything (3 uA standby).
ACC alone holds SYS_EN ~5 s (100k x 47 uF) so a crank before the Pi boots doesn't drop power. BZT52C15 limits load dump on the cap.
Hung Pi: the BCM watchdog resets it, GPIO26 floats low (100k bleed), and the board powers off if the key is off.
5 V BUCK: Pi, display, fans, 3.3 V
fSW 400 kHz (RT 33.2k), FPWM + spread spectrum. UVLO on 6.0 V / off 4.3 V (100k / 26.7k), rides through cranking dips.
VOUT = 1.0 V x (1 + 100k / 24.9k) = 5.02 V. Input ceramics 50 V X7R; the amp's PVDD bulk on +12V_PROT doubles as CIN-BLK.
AGND ties to PGND at the IC only. Keep the VIN/PGND hot loop through the 100 nF caps tight (SNVSB70F 11.1).
DEBUG UART + MOUNTING
Pi holes are isolated per the HAT spec; the amp heatsink screws ground the heatsink.
UART: 3.3 V, GPIO14/15 serial console. Header not fitted: solder one on if needed.
AMPLIFIER: TAS6424E-Q1, 4 x BTL, I2S from the Pi
10 x 12.5 mm, 50 V, 105 C
I2S stereo on SDIN1 and SDIN2 (rear = front); per-channel volume registers do the fader. MCLK 256 fs from the audio clock block.
~{STANDBY} / ~{MUTE} have 100k internal pull-downs: the amp stays silent until the Pi's I2C init. I2C address 0x6A.
Bypass bank: one 10 uF + 100 nF pair at each PVDD group (2/29/30, 42/43, 55/56), 1 uF at VBAT. Ceramics 50 V X7R.
HSSOP-56 thermal pad is on TOP: clamp a GND-bonded heatsink on it. AREF and AVSS are local returns, not GND.
OUTPUT FILTERS (2.1 MHz PWM -> speakers)
Inductors: 3.3 uH, Isat >= 6 A, DCR <= 50 mR (SLOSE73A 10.2.1.2.4). 1 uF 50 V X7R, 1 nF C0G.
Channel 1..4 = RL, RR, FL, FR (matches J1 order on the board). SDIN1 = SDIN2; fader via per-channel volume.
FANS (2 x Noctua 5 V PWM)
PWM from the Pi's hardware PWM (GPIO12/13) at 25 kHz, inverted by the FET. Tach: 2 pulses per turn.
Fan PWM inputs float high inside the fan: no Pi, full speed.

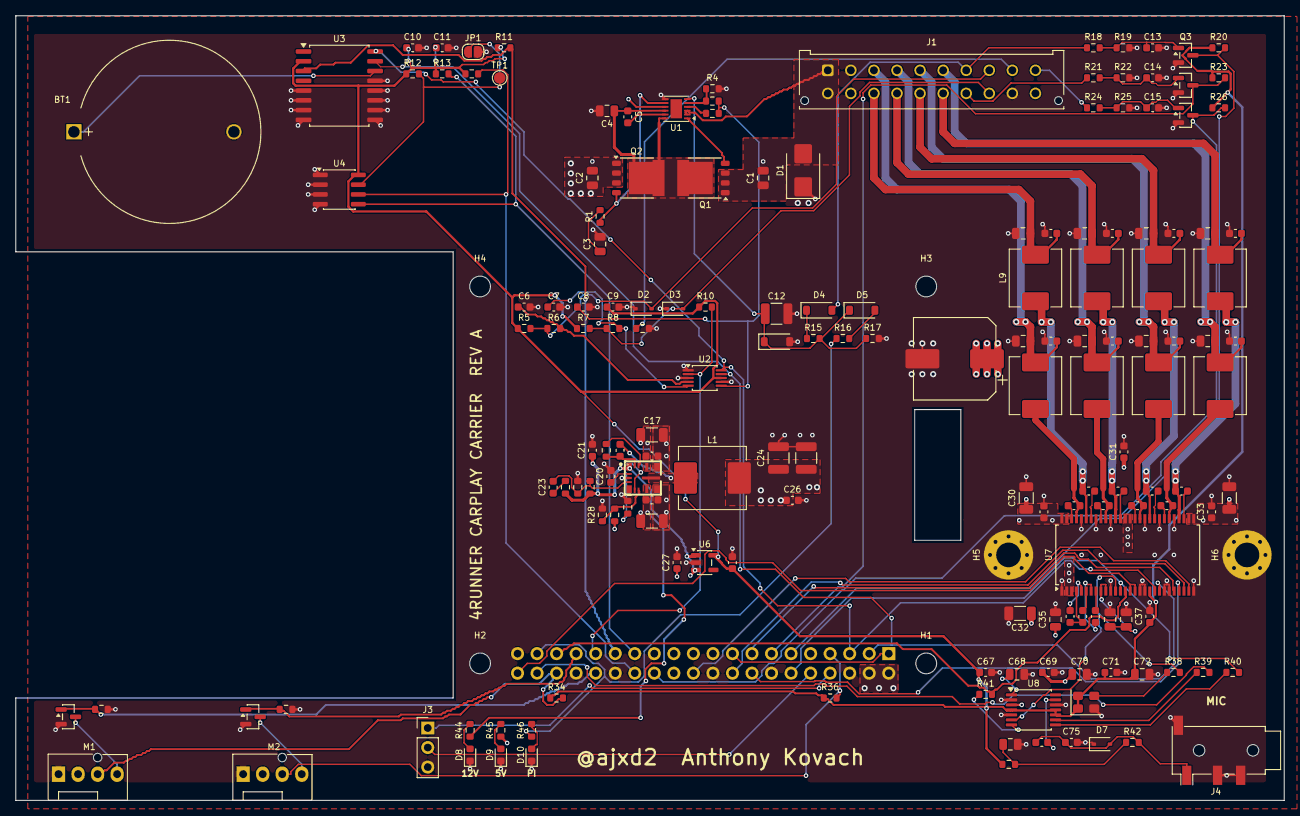
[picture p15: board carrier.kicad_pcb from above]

Board: 4 copper layers, 164.9 x 102.0 mm, 171 parts (1 on the bottom side), 105 nets.

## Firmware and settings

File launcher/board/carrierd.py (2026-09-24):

#!/usr/bin/env python3
"""carrierd: runs the carrier board (hardware/carrier).

  - brings the TAS6424 amp up once the audio clocks run, applies fader,
    watches FAULT/WARN, recovers latched faults, trims volume when hot
  - reads the steering-wheel ladders (ADS1115) and turns presses into
    CarPlay keys / launcher volume; learn mode maps a new wheel
  - key off for 8 s -> mute, standby, poweroff (gpio-poweroff then drops
    PI_HOLD and the board switches itself off)
  - headlights -> launcher night mode; reverse -> duck the music
  - fan curve from the SoC temperature, tach readback

Local JSON API on 127.0.0.1:8735 for the launcher UI:
  GET  /state
  POST /learn/start | /learn/skip | /learn/cancel
  POST /fader {"fader": -1..1, "balance": -1..1}
  POST /actions {"vol_up": ["volume", 4], ...}

  python3 -m board.carrierd            (from launcher/, on the Pi)
  python3 -m board.carrierd --sim      (desktop: simulated hardware)
"""
import argparse
import json
import logging
import os
import signal
import subprocess
import sys
import threading
import time
import urllib.request
from http.server import BaseHTTPRequestHandler, ThreadingHTTPServer

sys.path.insert(0, os.path.dirname(os.path.dirname(os.path.abspath(__file__))))
from board import fans, hw, power, swc, tas6424  # noqa: E402

log = logging.getLogger("carrierd")

CONFIG = os.path.expanduser("~/.config/carrierd/config.json")
LAUNCHER = "http://127.0.0.1:8734"
API_PORT = 8735

# BCM GPIO numbers (hardware/carrier/tools/gen_sch.py PI_GPIO)
GPIO = dict(acc=17, lights=27, reverse=7, amp_stby=22, amp_mute=23, amp_fault=24,
            amp_warn=25, adc_alert=6, fan1_tach=16, fan2_tach=4)
PWM_CH = dict(fan1=0, fan2=1)                         # GPIO12 / GPIO13

DEFAULT_ACTIONS = {
    "vol_up": ["volume", 4],
    "vol_down": ["volume", -4],
    "seek_up": ["key", "m"],                          # react-carplay: next = KeyM
    "seek_down": ["key", "n"],                        # prev = KeyN
    "mode": ["toggle_play"],                          # play = KeyP, pause = KeyO
    "voice": ["key", "h"],                            # home
}
DEFAULTS = {"buttons": {}, "actions": DEFAULT_ACTIONS, "fader": 0.0, "balance": 0.0,
            "reverse_duck_db": -12.0, "carplay_window_class": "react-carplay"}


def load_config():
    cfg = json.loads(json.dumps(DEFAULTS))
    try:
        with open(CONFIG) as f:
            cfg.update(json.load(f))
    except (OSError, ValueError):
        pass
    return cfg


def save_config(cfg, sim=False):
    data = json.dumps(cfg, indent=2) + "\n"
    if sim:
        os.makedirs(os.path.dirname(CONFIG), exist_ok=True)
        with open(CONFIG, "w") as f:
            f.write(data)
        return
    import persist
    os.makedirs(os.path.dirname(CONFIG), exist_ok=True)
    if not persist.write_through(CONFIG, data):
        log.error("could not persist %s", CONFIG)


def launcher_post(path, data):
    req = urllib.request.Request(LAUNCHER + path, json.dumps(data).encode(),
                                 {"Content-Type": "application/json"})
    try:
        with urllib.request.urlopen(req, timeout=2) as r:
            return json.load(r)
    except OSError as e:
        log.warning("launcher %s: %s", path, e)


class Board:
    def __init__(self, sim=False):
        self.sim = sim
        self.cfg = load_config()
        if sim:
            from board import sim as simdev
            self.bus = hw.SimI2CBus(simdev.devices())
            gpio = lambda n, mode, **kw: hw.SimGpioLine(n, mode, **kw)  # noqa: E731
            pwm = hw.SimPwm
        else:
            self.bus = hw.I2CBus(1)
            gpio = lambda n, mode, **kw: hw.GpioLine(n, mode, **kw)  # noqa: E731
            pwm = hw.Pwm
        # active-low inputs; the board pulls them up, the Pi's pull-up just agrees
        self.acc = gpio(GPIO["acc"], "in", pull="up")
        self.lights = gpio(GPIO["lights"], "in", pull="up")
        self.reverse = gpio(GPIO["reverse"], "in", pull="up")
        self.amp = tas6424.Amp(self.bus,
                               standby=gpio(GPIO["amp_stby"], "out", value=0),
                               mute=gpio(GPIO["amp_mute"], "out", value=0),
                               fault=gpio(GPIO["amp_fault"], "in", pull="up"),
                               warn=gpio(GPIO["amp_warn"], "in", pull="up"))
        self.adc = swc.ADS1115(self.bus)
        self.buttons = swc.Buttons(self.cfg["buttons"], self.on_button)
        self.learner = None
        self.fans = [fans.Fan(pwm(PWM_CH[f]), gpio(GPIO[f + "_tach"], "edge", pull="up"))
                     for f in ("fan1", "fan2")]
        self.key = power.KeyWatcher(self.shutdown)
        self.lights_on = power.Latched(1.0)
        self.lights_avg = power.Averager()
        self.in_reverse = power.Latched(0.3)
        self.playing_toggle = False
        self.status = {}
        self.amp_retry_at = 0.0
        self.amp_backoff = 2.0
        self.lock = threading.Lock()
        self.stop = threading.Event()

    # -- actions -----------------------------------------------------------
    def on_button(self, name, repeat):
        act = self.cfg["actions"].get(name)
        log.info("button %s%s -> %s", name, " (repeat)" if repeat else "", act)
        if not act:
            return
        kind = act[0]
        if kind == "volume":
            launcher_post("/api/volume", {"delta": act[1]})
        elif kind == "key":
            self.send_key(act[1])
        elif kind == "toggle_play":
            self.playing_toggle = not self.playing_toggle
            self.send_key("o" if self.playing_toggle else "p")

    def send_key(self, key):
        if self.sim:
            log.info("(sim) key %s", key)
            return
        cls = self.cfg["carplay_window_class"]
        env = dict(os.environ, DISPLAY=os.environ.get("DISPLAY", ":0"))
        subprocess.run(["xdotool", "search", "--limit", "1", "--class", cls, "key", "--window", "%1", key],
                       env=env, capture_output=True)

    def shutdown(self):
        log.warning("key off: shutting down")
        self.amp.stop()
        if not self.sim:
            subprocess.run(["sudo", "systemctl", "poweroff"])

    # -- loops ---------------------------------------------------------------
    def sample_wheel(self):
        for ch in (0, 1):
            try:
                v = self.adc.read(ch)
            except OSError:
                return
            with self.lock:
                if self.learner:
                    self.learner.feed(ch, v)
                    if self.learner.done:
                        self.cfg["buttons"] = self.learner.learned
                        self.buttons.buttons = self.cfg["buttons"]
                        save_config(self.cfg, self.sim)
                        self.learner = None
                else:
                    self.buttons.feed(ch, v)

    def poll_inputs(self):
        acc_on = not self.acc.get()
        left = self.key.update(acc_on)
        frac = self.lights_avg.feed(not self.lights.get())
        if self.lights_on.update(frac >= power.LIGHTS_ON_FRACTION):
            launcher_post("/api/dim", {"dimmed": self.lights_on.value})
        if self.in_reverse.update(not self.reverse.get()):
            self.amp.set_duck(self.cfg["reverse_duck_db"] if self.in_reverse.value else 0.0)
        self.status.update(acc=acc_on, shutdown_in=left, lights=self.lights_on.value,
                           reverse=self.in_reverse.value)

    def tick(self):
        now = time.monotonic()
        st = self.status
        if not self.amp.playing and now >= self.amp_retry_at:
            try:
                ok = self.amp.start()
            except OSError as e:
                ok, st["amp_error"] = False, str(e)
            if ok:
                self.amp_backoff = 2.0
                self.amp.set_fader(self.cfg["fader"], self.cfg["balance"])
            else:
                self.amp_retry_at = now + self.amp_backoff
                self.amp_backoff = min(self.amp_backoff * 2, 60.0)
        amp = {}
        if self.amp.playing:
            try:
                amp = self.amp.check()
            except OSError as e:
                amp = {"error": str(e)}
            if amp.get("fault"):
                log.warning("amp fault %s; restarting in %.0f s", amp.get("faults"), self.amp_backoff)
                self.amp.stop()
                self.amp_retry_at = now + self.amp_backoff
                self.amp_backoff = min(self.amp_backoff * 2, 60.0)
            self.amp.set_thermal_cut(-6.0 if amp.get("overtemp_warning") else 0.0)
        temp = fans.cpu_temp()
        duty = fans.fan_duty(temp, bool(amp.get("overtemp_warning")))
        rpm = []
        for f in self.fans:
            f.set(duty)
            rpm.append(f.poll_tach())
        st.update(amp=amp, amp_playing=self.amp.playing, cpu_temp=temp, fan_duty=round(duty, 2),
                  fan_rpm=rpm)

    def run(self):
        last_in = last_tick = 0.0
        while not self.stop.is_set():
            self.sample_wheel()
            now = time.monotonic()
            if now - last_in >= 0.05:
                self.poll_inputs()
                last_in = now
            if now - last_tick >= 1.0:
                self.tick()
                last_tick = now
            if self.sim:
                time.sleep(0.01)

    # -- API -------------------------------------------------------------------
    def state(self):
        with self.lock:
            return dict(self.status, buttons=self.cfg["buttons"], actions=self.cfg["actions"],
                        fader=self.cfg["fader"], balance=self.cfg["balance"],
                        learn=self.learner.state if self.learner else None)

    def api(self, path, data):
        with self.lock:
            if path == "/learn/start":
                self.learner = swc.Learner()
            elif path == "/learn/skip" and self.learner:
                self.learner.skip()
            elif path == "/learn/cancel":
                self.learner = None
            elif path == "/fader":
                self.cfg["fader"] = max(-1.0, min(1.0, float(data.get("fader", self.cfg["fader"]))))
                self.cfg["balance"] = max(-1.0, min(1.0, float(data.get("balance", self.cfg["balance"]))))
                self.amp.set_fader(self.cfg["fader"], self.cfg["balance"])
                save_config(self.cfg, self.sim)
            elif path == "/actions":
                self.cfg["actions"].update({k: v for k, v in data.items() if k in swc.LEARN_ORDER})
                save_config(self.cfg, self.sim)
            else:
                return None
        return self.state()


def serve(board):
    class H(BaseHTTPRequestHandler):
        def log_message(self, *a):
            pass

        def _json(self, code, obj):
            body = json.dumps(obj).encode()
            self.send_response(code)
            self.send_header("Content-Type", "application/json")
            self.send_header("Content-Length", str(len(body)))
            self.end_headers()
            self.wfile.write(body)

        def do_GET(self):
            if self.path == "/state":
                self._json(200, board.state())
            else:
                self._json(404, {"error": "not found"})

        def do_POST(self):
            n = int(self.headers.get("Content-Length") or 0)
            try:
                data = json.loads(self.rfile.read(n) or b"{}")
            except ValueError:
                return self._json(400, {"error": "bad json"})
            out = board.api(self.path, data)
            self._json(200 if out is not None else 404, out or {"error": "not found"})

    srv = ThreadingHTTPServer(("127.0.0.1", API_PORT), H)
    threading.Thread(target=srv.serve_forever, daemon=True).start()
    return srv


def main():
    ap = argparse.ArgumentParser()
    ap.add_argument("--sim", action="store_true", help="simulated hardware")
    args = ap.parse_args()
    logging.basicConfig(level=logging.INFO, format="%(asctime)s %(name)s: %(message)s")
    board = Board(sim=args.sim)
    serve(board)

    def quit_(signum, frame):
        # systemd stop / halt: mute and park the amp before power goes
        log.info("signal %d: amp to standby", signum)
        board.stop.set()
        board.amp.stop()
        sys.exit(0)

    signal.signal(signal.SIGTERM, quit_)
    signal.signal(signal.SIGINT, quit_)
    board.run()


if __name__ == "__main__":
    main()

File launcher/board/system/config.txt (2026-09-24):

# Carrier board: append to /boot/firmware/config.txt (under [all]).
# The board's ID EEPROM can carry the same overlays once programmed.

dtparam=i2c_arm=on
dtparam=audio=off

# PI_HOLD (GPIO26) high as early as the firmware can, then held by
# gpio-poweroff until the kernel halts; the board cuts power ~2 s later.
gpio=26=op,dh
dtoverlay=gpio-poweroff,gpiopin=26,active_low=1

# DS3231 RTC on I2C-1 (0x68): the clock survives power off
dtoverlay=i2c-rtc,ds3231

# Serial console on the board's debug header J3 (GPIO14/15, 115200, 3.3 V)
enable_uart=1

# Audio: Pi I2S as clock consumer, 48 kHz stereo out to the amp, mic in from
# the PCM1808 on GPIO20 (see carrier-audio-overlay.dts)
dtoverlay=carrier-audio

# Fan PWM on GPIO12/13 (pwmchip0 channels 0/1)
dtoverlay=pwm-2chan,pin=12,func=4,pin2=13,func2=4

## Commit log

2026-07-19 Style notifications to match Plymouth theme, sharpen critical alerts
    dunst popups now use a dark minimal look (black background, thin gray
    frame) matching the boot splash instead of dunst's default styling.
    Critical thermal alerts break from that on purpose: dark red fill, a
    thicker red frame, a warning glyph, and an audible tone, since a red
    border alone was too easy to miss while driving. Also fixes deploy.sh
    (pkill was matching its own invoking shell via substring, killing the
    SSH session instead of the target process) and removes em dashes
    throughout per user preference.
    Claude-Session: https://claude.ai/code/session_01MEs3ANv22xCm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
2026-07-19 Add a launcher: CarPlay becomes one app among others
    Replaces the direct CarPlay autostart with a home screen (launcher.py)
    that shows CarPlay, Flappy Bird, and a live system-status app as tiles.
    Apps are hidden rather than killed when you switch away, so CarPlay
    keeps playing in the background and there's no reconnect delay coming
    back to it. A small always-on-top touch tab (overlay_tab.py, a raw X11
    override-redirect window, the same trick dunst notifications already
    rely on) is the "go home" control, since the car has no keyboard.
    CarPlay explicitly keeps audio priority: its sink-input is never muted
    by app switching, whatever else is active gets muted instead.
    Also removes the old `whi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
2026-07-20 Add dongle icon-customization tool and document USB protocol findings
    set_dongle_icon.py talks directly to the CPC200-CCPA dongle's own wire
    protocol to set a custom home-screen icon/label on the phone. INFO.md
    now documents what's readable/writable on the dongle (including the
    full paired-device list), confirms there's no device-removal command,
    and why alternate firmware isn't worth the activation-lock brick risk.
2026-07-20 Add a Devices launcher app to manage the dongle's paired phones
    The Carlinkit CPC200-CCPA exposes no paired-device removal over its USB
    wire protocol; the only way to edit the list is its own web admin panel
    (POST /cgi-bin/server.cgi, a signed API reverse-engineered from the
    panel JS and verified against captured traffic). This adds:
    - launcher/dongle.py: signs and calls the panel API, and manages the
    on-demand wlan0 join to reach it (the panel is only on the dongle's
    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
2026-07-20 Paginate the launcher grid: 4 tiles per screen with a bottom pager
    Adding the Devices tile made six tiles cram into one row. Cap the grid at
    4 tiles per screen and add a bottom pager (prev/next chevrons + page
    dots) to move between screens. Uses explicit page rendering rather than a
    horizontal scroll, which avoids the overlap/snap issues when the tile
    count isn't a multiple of 4, and the 3s running-state refresh now updates
    borders in place instead of rebuilding (so it never fights the pager).
    Verified on the touchscreen: page 1 = CarPlay/Flappy/Info/Trip, page 2 =
    Logs/Devices, dots and prev/next disabled-states correct.
    Claude-Sessi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
2026-09-22 Fix launcher reliability bugs, persist runtime state, fix CarPlay audio
    - Phones view can no longer strand wlan0 on the dongle AP (generation
    counter on connect/disconnect; restore on server startup)
    - server.py kills stale Chromium/CarPlay from a previous run, so a
    respawn never runs two CarPlays against the dongle
    - Window capture survives X window-id reuse after an app restart
    - deploy.sh cooperates with the autostart respawn loop and rewrites files
    in place so the running overlay sees them
    - persist.py: write-through to /media/root-ro for launcher config, trip
    state, volume, and react-carplay's own config.json
    - Volume is restored on boot and saved once a change settles
    - tools/p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
    [ccpa_panel.py, patch_carplay_audio.py]
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2026-09-22 WIP carrier schematic: generator engine, harness and input protection
    schlib.py writes KiCad 10 schematics with exact pin math (verified via ERC
    across every rotation/mirror); gen_sch.py builds the sheet section by
    section. Harness and LM74800 input protection are done; buck, 3.3 V,
    power-hold, Pi header, amp, SWC/ADC, RTC/EEPROM, fans still to come.
    [carrier.kicad_sch]
2026-09-23 Carrier schematic: 5 V buck, 3.3 V LDO, power hold, key sense, Pi header
    Claude-Session: https://claude.ai/code/session_01EoLoLi7g91W5u4w3UzwQgu
    [carrier.kicad_sch]
2026-09-23 Carrier schematic: amplifier, output filters, SWC ADC, RTC, ID EEPROM, fans, MCLK option
    Also fixes field justification on 180-degree fields in the schematic
    writer and re-lays out the sheet so every section fits the A2 frame.
    ERC is clean.
    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
    [carrier.kicad_sch]
2026-09-23 Carrier schematic: add the 470 uF PVDD bulk capacitor
    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
    [carrier.kicad_sch]
2026-09-23 Carrier: pick every part, add MPN/Manufacturer/LCSC fields
    All fitted parts are in JLCPCB stock. Swaps made while picking:
    100 V caps upstream of the load-dump cutoff, a C0G 1 nF in the speaker
    filters, 15 V ESD diodes on the wheel inputs (survive a short to 12 V),
    33 pF crystal load caps, and footprints matched to the chosen inductors
    and coin cell holder. The debug UART header is left unfitted.
    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
    [carrier.kicad_sch]
2026-09-23 Carrier: add a reverse-gear input (harness pin 10 to GPIO20)
    Same 12 V sense circuit as ACC and ILLUM, active low into the Pi, for
    an automatic backup camera or a music duck while reversing.
    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
    [carrier.kicad_sch]
2026-09-24 Carrier: vertical harness connector, deterministic schematic UUIDs
    The harness plug now faces straight out of the board (toward the
    firewall): Molex 43045-2012, LCSC C485575. Symbol and pin UUIDs are
    derived from the reference so the PCB stays linked across regenerations.
    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
    [carrier.kicad_sch]
2026-09-24 Carrier: board generator (footprints, nets, 4-layer rules, net classes)
    tools/gen_pcb.py builds carrier.kicad_pcb from the schematic netlist inside
    the KiCad flatpak; parts are parked below the outline until placement.
    The buck switch node gets an SW_5V label so the PCB rules can name it.
    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
    [carrier.kicad_pcb, carrier.kicad_sch]
2026-09-24 Carrier PCB: Pi geometry from the HAT spec, amplifier block placement
    J2 sits on the bottom with pin 1 over the Pi's pin 1 (checked by pad
    position), H1-H4 on the Pi hole pattern and isolated per the HAT spec,
    USB/Ethernet notch and display-flex cutout follow the Pi's position
    (provisional until measured). The TAS6424 block follows TI's EVM layout.
    Parts carry a Section field so placement finds them by block and net.
    Boot caps move to 0603 to fit the 0.635 mm pitch.
    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
    [carrier.kicad_pcb, carrier.kicad_sch]
2026-09-24 Carrier PCB: place harness, input protection and 5 V buck blocks
    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
    [carrier.kicad_pcb]
2026-09-24 Carrier PCB: place the remaining circuits; every part on the board
    RTC, coin cell and ID EEPROM over the Pi, key/lights/reverse sensing and
    the wheel ADC beside J1's control pins, fan headers on the bottom edge.
    U8 uses the 3x3 TSSOP-10 land pattern (same MO-187 package, wider gaps).
    DRC: no overlaps or clearance errors; routing still to do.
    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
    [carrier.kicad_pcb, carrier.kicad_sch]
2026-09-24 Carrier: board becomes the I2S clock master; amp heatsink design
    The Pi's PCM block carries only two channels, so TDM4 cannot feed four
    amp channels, and the TAS6424 needs a real MCLK (128-512 fs) outside
    TDM. A 12.288 MHz oscillator now drives the amp's MCLK and a PCM1808-Q1
    in master mode (MD1 = MD0 = 1) divides it to BCK = 64 fs and LRCK =
    48 kHz; the Pi runs its I2S port as a clock consumer. SDIN2 takes the
    same data as SDIN1, so the rear speakers play the front stereo pair and
    the amp's per-channel volume does the fader. The commercial-grade
    CS2100 option is gone.
    tools/heatsink.py models a CNC aluminium heatsink after TI's EVM part
    (20 x 41.4 mm, four 25 mm fins, feet on the grounded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
    [carrier.kicad_pcb, carrier.kicad_sch, heatsink.step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]
2026-09-24 Add carrierd: services for the carrier board
    Amp bring-up in the datasheet's order (PHASE_SEL before leaving standby,
    faults cleared and checked before PLAY), fader and balance through the
    per-channel volume registers, fault recovery with backoff, thermal trim.
    Steering-wheel ladders via the ADS1115 with debounce, hold-to-repeat and
    a learn mode that rejects buttons it cannot tell apart. Key-off shutdown
    after 8 s so cranking dropouts are ignored, headlights to night mode
    (PWM dimmers averaged), reverse ducks the music, fan curve with tach.
    Standard library only: I2C through I2C_RDWR and GPIO through the chardev
    v2 uAPI, with the request struct checked byte for byte against
    <linux/gpio.h> i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
    [config.txt]
2026-09-24 Carrier: measured Pi position, re-floorplan, 3D stack-up
    The Pi's spot on the Hosyond display, measured from the maker's back-view
    drawing scaled by the Pi's own 58 x 49 mm hole pattern: holes at x 58.8 /
    116.8, y 35.1 / 84.1 from the display's top-left corner (back view), Pi
    turned 180 degrees with the ports toward the screen's right. The pogo
    pads line up with GPIO 2/4/6, which confirms it.
    The Pi sits mid-screen, so the board gets a notch from the port block to
    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
    [carrier.kicad_pcb]
2026-09-24 Carrier: document the board before routing
    hardware/carrier/README.md covers each circuit block and why it was
    chosen, the Pi position and where that number came from, the stack-up,
    harness wiring, the GPIO map, the shopping list, regeneration commands,
    verification status and open items. The root README and INFO.md now
    point to it. Two amp schematic notes still described the old TDM plan
    and now match the I2S clock-master design. TI's EVM guide is added to
    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
    [carrier.kicad_sch]
2026-09-24 Carrier: route the board
    Four layers: In1 solid GND, In2 split between +12V_PROT and +5V. Power
    paths are pours and hand-placed tracks (battery path, buck loop, amp
    PVDD, the Pi's 5 V pins); the amp outputs and speaker tracks are routed
    by script, P legs on top and M legs under the coils, speaker lanes
    nested so none cross. Every GND pad has its own via to the plane. The
    rest goes through Freerouting, with a small grid router for the tight
    spots. Nothing copper within 3 mm of the outer edge, so a small error in
    the Pi position only moves the outline. DRC: 0 errors, 0 unrouted.
    Changes made along the way:
    - amp channels remapped (ch1..4 = RL, RR, FL, FR) and the harness
    speaker pins reorde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
    [carrier.kicad_pcb, carrier.kicad_sch, fit_plate.step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]
2026-09-24 Carrier: 3D models for the harness plug and coin holder, credit text
    KiCad ships no model for the Micro-Fit 43045 or the MYOUNG CR2032
    holder: STEP models from LCSC/EasyEDA in lib/3d, placed on KiCad's
    footprint origins. Top silkscreen credit in the bottom strip.
    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
    [carrier.kicad_pcb]
2026-09-24 Carrier: board name and revision, message on the underside
    Top: 4RUNNER CARPLAY CARRIER REV A up the strip beside the Pi. Underside,
    facing the Pi: NO FIDDLING WHILE DRIVING, the board's spec and date.
    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
    [carrier.kicad_pcb]
2026-09-24 Carrier: mic input and status LEDs (board to be re-routed)
    Mic: 3.5 mm jack J4 (PJ-320D) with electret bias from +3V3 (1k + 10 uF
    filter, 2.2k), ESD and 1 nF at the jack, 1 uF into the PCM1808's VINL.
    PCM1808 DOUT goes to the Pi's I2S input on GPIO20, so ~REVERSE moves to
    GPIO7. The overlay adds a capture codec on the same link; carrierd and
    the docs follow. Three red status LEDs: 12 V protected, 5 V, PI_HOLD.
    Serial console enabled for J3.
    Tooling: the maze router checks the stub from an exact pad point to its
    first grid cell; 0.5 mm keepout bands around the cable slot and notch;
    OUTLINE_SHIFT in place.py moves the outer edge after measuring; the build
    keeps a copy of the board right after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
    [carrier.kicad_sch, config.txt]
2026-09-24 Carrier: route with the mic and LEDs, outline from real measurements
    Measured on the screen (Pi edge to screen edge: 36.65 / 43.40 / 15.35 /
    31.45 mm): the outline moves 1.35 mm toward the ports; parts stay. The
    clock-parts row and the mic jack pulled in to keep copper 3 mm from the
    edges. DRC: 0 errors, 0 unrouted.
    Build: a repair pass deletes autorouted tracks that DRC flags as shorts
    or clearance errors and re-routes those links; CBOOT, EN/SYNC and
    I2S_FSYNC are pre-routed. CBOOT is placed by hand (its escape is off the
    router's grid). Fit plate regenerated with the corrected outline.
    Claude-Session: https://claude.ai/code/session_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
    [carrier.kicad_pcb, fit_plate.step, fit_plate.stl]
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2026-09-24 Carrier: fit_frame.stl, a 75% lighter fit test (rim, screw bosses, bars)
    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
    [fit_frame.stl]
2026-09-24 Carrier: outline from the manufacturer's drawing (164.9 x 102.0)
    The Hosyond drawing confirms the measured Pi position within 0.2 mm and
    gives the exact screen size; the outline is trimmed to match (it
    overhung the bottom by ~1.1 mm). Edge margin 2.5 mm now the Pi position
    is settled. DRC: 0 errors, 0 unrouted. The screen's corner holes are
    for the enclosure; no board change.
    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
    [carrier.kicad_pcb, fit_frame.stl, fit_plate.step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]
2026-09-24 Carrier: silkscreen tidy, harness pin table, JLCPCB order files
    Labels 0.8 mm, hidden where they clash with pads, labels or the edge
    (JLC places from the CPL). Harness pin table on the underside by J1.
    tools/jlc_export.sh writes fab/: Gerbers + drill zip, BOM (no ref
    ranges) and CPL; all 162 parts match between them.
    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
    [carrier.kicad_pcb, carrier_bom.csv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]
2026-09-24 Carrier: one BOM line per LCSC part (JLC left the second fan header unconfirmed)
    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
    [carrier_bom.csv]
2026-09-24 Carrier: CPL uses part centres (through-hole parts were placed by pin 1)
    JLC places by part centre; KiCad's origin on through-hole footprints is
    pin 1, so BT1, J1 and the fan headers showed offset in JLC's preview.
    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
    [carrier_cpl.csv]
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2026-09-25 Boot: autologin can't hang behind Plymouth; chroot initramfs builds; no flicker
    systemd 257 resets tty1 and asks it for its size before starting agetty,
    then waits for the reply. Plymouth holds tty1 in graphics mode, so on some
    boots nothing answered and the Pi sat on the splash for good. A getty@tty1
    override sets a fixed size and no reset.
    Initramfs builds in overlayroot-chroot need MODULES=most and FSTYPE=ext4;
    they now live in /etc/initramfs-tools/conf.d/overlayroot rather than a
    temporary copy in install.sh, so kernel updates get them too. INFO.md
    covers mounting the boot partition into the chroot for kernel updates,
    without which the new kernel would land in an empty directory.
    When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
2026-09-30 Carrier: pre-order fixes from simulation and a placement check
    Placement file: JLC places each part by its own footprint, and 16 of ours
    are drawn turned relative to KiCad's (SOT-23s, LFPAK56s, U2-U4, U6, U7,
    J1, the fan headers and the CR2032 holder, which would have gone in
    reversed). jlc_cpl.py now adds the rotation JLC needs and moves BT1 and J4
    to JLC's footprint origin (BT1 was 3.8 mm off, J4 0.9 mm). check_cpl.py
    fits JLC's footprints pad by pad and checks fab/carrier_cpl.csv: 0
    mismatches (the previous file fails 18).
    R15 47k -> 10k: with the key turned straight to START, the hold cap now
    fills in time and the board rides through a crank (4.6 s worst case, was
    0.5 s). R4 3.65k -> 3.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
2026-10-24 Pi: carrier board installer and full system upgrade script
    launcher/board/install.sh installs the board software through
    /media/root-ro with the progress card: i2c-tools and hwclock, i2c-dev at
    boot, board/ and carrierd.service, the audio overlay on the boot partition,
    and config.txt lines as one managed block (--audio adds the carrier audio
    overlay, --enable starts carrierd).
    launcher/upgrade.sh runs a full upgrade the INFO.md way (boot partition
    mounted into the chroot), backs up the boot partition first, checks the new
    initramfs, and reboots with shell builtins because dpkg leaves replaced
    programs unrunnable on the live overlay until then. apt is IPv4 only: the
    bench LAN's IPv6 route st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
2026-10-24 Carrier: bring-up log, amp bench tool, mic capture on its own I2S link
    The overlay now has one dai-link per direction. With both dummy codecs on
    one link, kernel 6.18 only offered playback, so the mic never appeared.
    It also carries the 32-bit slot fix (VERIFICATION.md finding A).
    board/amptest.py runs the TAS6424's DC load diagnostics and plays a
    distinct tone (or a file) on one channel at a time, capped at -30 dB.
    BRINGUP.md is the power-up procedure and the log of the first two boards:
    board 1 passes everything but its audio clocks (X1 or U8, to rework);
    board 2 passes power, I2C, inputs, all four amp channels at low level and
    the mic.
2026-10-27 Carrier: board as the default speaker and mic; harness plug diagram
    install.sh --audio now sets PulseAudio up for the board: carrier.pa opens
    the playback and capture PCMs at the fixed 48 kHz (udev-detect is told to
    skip the card; it only found the capture side, at 44.1 kHz), adds a mono
    mic source from the left ADC slot with +20 dB, makes both the defaults,
    and drops the USB adapter's set-default-sink from the user default.pa.
    It also remounts root-ro after overlayroot-chroot calls, which leave it
    read-only.
    tools/harness_diagram.py draws the J1 plug from the wire side with the
    Metra colours. README: the reverse-run wire is stranded pure copper.
2026-10-27 Info: Car tab with the carrier board's state
    Info now has System and Car tabs. Car shows battery voltage (charging,
    engine off, low), the amplifier (on, standby, fault, hot), the dash
    temperature, and key (with the key-off countdown), headlights, reverse,
    fans, audio output, clock source, learned steering-wheel buttons and the
    fader.
    carrierd reads the battery divider on ADS1115 AIN2 (x 11.77) and the
    DS3231's temperature once a second; server.py adds carrierd's state, the
    default sink and the clock source to /api/info. Without carrierd the Car
    tab says the board service isn't running.
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2026-10-27 Harness: wire colours from the Klintotour adapter's 16-pin Android end
    The plug is built from the adapter's Android end (plug cut off), which
    uses the EIA colours plus brown (KEY1, Toyota 20-pin #7) and brown/white
    (KEY2, #8) for the wheel and a pink BACK lead for reverse. The adapter
    already joins the wheel ground (#6) to black, so pin 9 stays empty.
    README and the diagram also ask for both +12 V pins and at least two
    grounds (loud peaks exceed one contact's rating), a short check before the
    first plug-in, and note the adapter does not suit JBL trucks. The
    diagram's notes no longer run off the bottom of the image.
2026-10-28 Settings: learn the steering wheel buttons on the touchscreen
    A Steering wheel buttons row in Settings shows how many buttons are
    learned and starts learn mode. The panel asks for each button in turn
    (volume, track, mode, voice, phone), ticks each one off, shows carrierd's
    "reads the same as" refusal, and has Skip and Cancel; leaving Settings
    mid-way cancels it. server.py proxies /api/wheel to carrierd, whose port
    the page can't reach directly.
    carrierd keeps the previous buttons when every button is skipped instead
    of saving an empty set.
2026-10-28 Volume bar follows wheel presses at once; wider steering-wheel tolerances
    The home screen learned the volume from its 2 s status poll, so a
    steering-wheel press changed the sound at once but moved the bar up to 2 s
    later. /api/volume/wait now holds the request until the volume changes
    (set_volume reports every change made through the launcher; the 4 s
    persistence check catches the rest) and the page waits on it in a loop.
    swc: a 2007 4Runner wheel drifts while a button is held (seek-down
    0.83 -> 1.25 V over 3 s) and its buttons sit about 0.1, 1.0, 1.66 and
    2.55 V apart, so learning now accepts a press steady to 0.3 V (was
    0.06), presses match the nearest learned button within 0.25 V, and le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
2026-10-28 carrierd: wheel keys reach CarPlay (focus the visible window, then type)
    Next/previous track did nothing. react-carplay reads keydown in its page,
    and Chromium ignores the synthetic event xdotool key --window sends; the
    first window of the class was also a hidden 10 x 10 helper. carrierd now
    finds the visible CarPlay window (largest viewable one), focuses it and
    types the key, which react-carplay logs and acts on. With CarPlay hidden
    behind the launcher, the key is logged and skipped.
2026-10-28 Wheel track keys reach CarPlay even behind the launcher
    The launcher starts react-carplay with --remote-debugging-port=9229
    (Chromium binds it to 127.0.0.1). carrierd opens CarPlay's page over that
    DevTools port with a small stdlib WebSocket client and dispatches the
    keydown react-carplay's own handler listens for (KeyM next, KeyN prev, per
    its config.json bindings), so seek works whether CarPlay is on screen or
    hidden. Without the port it falls back to focusing the visible CarPlay
    window and typing.
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2026-10-28 Update view: full screen first, tap to shrink to the card; start chime
    Deploys now open a full-screen update view (title, large percentage, bar,
    message, Keep the power on, Hide) that a tap shrinks to the existing
    compact card; tapping the card brings it back. Done and failed show in
    both forms. A short three-note chime (G5 C6 E6, 1.1 s, -12 dBFS) plays
    through PulseAudio when the view opens and a softer two-note one when the
    update finishes; no sound is not an error. make_chime.py generates both
    WAVs (48 kHz, the car's fixed rate). progress.sh keeps its interface and
    copies the WAVs next to xsplash.py.
    xsplash.py sends images in 64-row strips: python-xlib's put_pil_image
    painted black belo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
2026-10-28 Equalizer: 7 bands from the volume bar, run in PulseAudio
    An EQ button on the home screen's volume bar opens the Equalizer view:
    seven bands (60 Hz to 14 kHz, +/-12 dB), presets (Flat, Bass, Vocal,
    Treble, Loudness), applied live while dragging and saved to eq.json once
    left alone, restored when the launcher starts.
    Audio path: carrier.pa adds a module-ladspa-sink carrier_eq with
    swh-plugins' 15-band mbeq in front of the board's sink and makes it the
    default (the board itself stays the default if the plugin fails to load).
    eq.py spreads the seven bands over mbeq's fifteen in log frequency, lowers
    everything by the largest boost so full volume can't clip, and sets the
    gains over PulseAudio's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
2026-10-29 carrierd: fan rpm no longer capped at ~240
    Tach edges were read once a second, 16 events per read, so every fan
    read about 240 rpm (a fan at 25 % turns ~1150). GpioLine.events() now
    drains the queue, and the main loop (~100 Hz, for the wheel) polls the
    tach lines on every pass so the kernel's 16-event queue never overflows.
    On the Pi: 4792 / 4584 rpm at full speed, as the bench test measured.
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
